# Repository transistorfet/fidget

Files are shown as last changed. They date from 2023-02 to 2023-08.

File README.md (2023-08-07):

Fidget - The FPGA Widget
========================

###### *Started January 5, 2023*

This project is an experiment in making a board using a Lattice iCE40 FPGA in a surface mount
package (LQFP-144).  It has bus connectors to allow it to be hooked up to one of the
[Computie](https://jabberwocky.ca/projects/computie/) single board computers, to be used as either a
debug monitor to replace the arduino supervisor, or as a generic expansion device for the computers.
I'd also like to be able to use it more generically as well, for example as a logic analyzer, which
is why it's called a widget.

It needs to have bus transceivers to level convert between the 5V signals of the Computie expansion
bus, and the 3.3V I/O pins of the FPGA.  To save on I/Os, the address and data bus lines are
multiplexed using the level-converting transceivers.  I also added the latches necessary to make a
request on the bus.  Without the latches, the device will only be able to receive bus requests but
not make them.

The basic design of the USB and power supply circuitry was mostly copied from the [TinyFPGA
BX](https://www.crowdsupply.com/tinyfpga/tinyfpga-ax-bx) development board.  I bought one back in
early 2020, and have an environment set up for developing for it.  I was able to reuse the
bootloader and upload utility from that to accelerate the bring-up of this board.  I highly
recommend checking it out, especially since it sounds like they will have more boards for sale soon
in 2023.  It's an excellent affordable open source board which is great for experimenting with
verilog and FPGAs.

The schematics can be seen online
[here](https://github.com/transistorfet/fidget/blob/main/hardware/Fidget/Fidget.pdf) or in KiCAD.

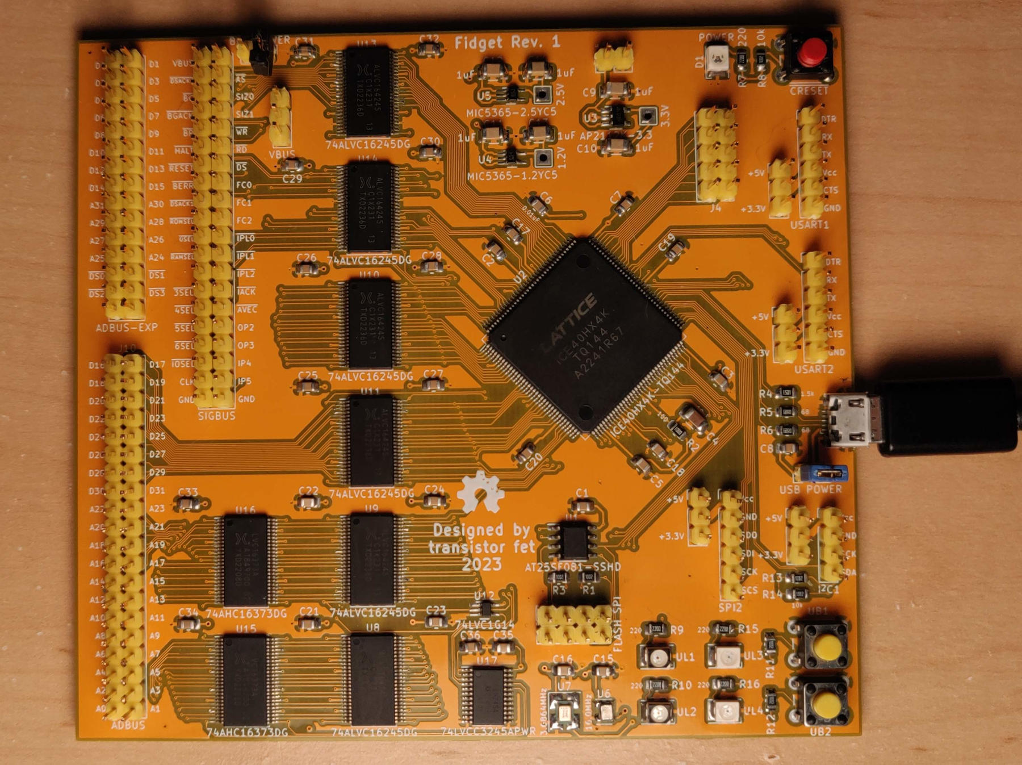
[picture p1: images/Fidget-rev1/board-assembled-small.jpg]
Fidget Revision 1, assembled and working


This repository uses submodules, and can be cloned using:
```
git clone --recurse-submodules git@github.com:transistorfet/fidget.git
```

Building the Board
------------------

It was surprisingly easy to build, although my attempts at documenting the soldering of the
transceivers resulted in more mistakes than it was worth.  I had solder bridges on every chip that
required some solder wick, and I had a few chips that were crooked enough that I decided to just use
the hot air rework station to remove them and resolder them.  The FPGA was actually much easier to
solder by comparison.  The other parts I had trouble with were the oscillators, which come in a
module on a tiny circuit board with castellated pins on the edges.  The 3.6864 Mhz one was easy
because the footprint turned out to be way bigger than the chip, but the 16 MHz one was the right
size for the part but with not enough clearance for hand soldering.  In future revisions I'll have
to make the footprint bigger.

I started with the 3.3V regulator and tested it with a bench power supply at 5V to verify that I was
getting 3.3V output, which is used by the transceivers.  I then soldered the transceivers and
latches at once, along with their caps, and tested at the end of that.  I put the SPI flash and
oscillators on and tested those with the bench supply to make sure I was getting signal.  The 16 Mhz
oscillator needed a lot of reworking and desoldering.

With the SPI flash chip in, I programmed it (see below).  I also put the other voltage regulators in
and tested them before soldering the FPGA.  With the all the power good, I put the other LEDs,
buttons on, as well as the FPGA itself with its associated caps.  After checking for shorts, I
tested it to see what would happen.  Surprisingly it worked, with the bootloader slowly blinking one
of the LEDs to indicate it was running, so the configuration I had written to the flash chip was
good.  I then put on the remaining headers which were the last components to solder.

At the end, and between the two days I was assembling, I cleaned the flux off with a toothbrush and
some soap and/or rubbing alcohol.  I then blow dried the board to make sure the water under the
chips was dry before it had a chance to corrode any pins.  It's best to not get the board too hot
when doing this.

I like to use water soluble liquid flux.  The No Clean stuff is much harder to clean up after, but
it doesn't have to be cleaned off, where as the water soluble stuff can corrode the pins if it's not
cleaned off, but works better and is easy to clean.

For soldering, I use a soldering tip that's cone-shaped but cut off at an angle to form a large flat
surface.  It heats the pad on the board better than a round tip, which gives a good solder
connection for SMT components, even though it's wider than individual pins.  The solder mask and
flux make the solder flow well and not bridge.  I have a Quick 861DW hot air rework station for when
I make mistakes, but I only needed to use it twice, once to remove the 3 crooked
transceivers/latches, which probably would have been ok if I had left them, and once to remove the
16 MHz oscillator.

Initializing the Board
----------------------

To load the initial bootloader, I used [spi-flash-programmer](https://github.com/nfd/spi-flash-programmer)
and an [AdaFruit QT Py](https://www.adafruit.com/product/4600) I had laying around, which just
happened to be the most convenient 3.3V Arduino-compatible board I had available, but any 3.3V
Arduino will do.  I uploaded the flash programmer to it, but I needed to adjust the SPI speed
because the default was too high for the long dupont wires I used to connect it to Fidget.

I programmed the SPI chip in circuit before I soldered the FPGA in place, just in case they
interfered, which was a good idea because they did interfere.  With the FPGA in circuit, the RESET
button needs to be held for the duration of SPI programming (preferably for the whole time the
Arduino is connected), or it won't work.

I connected the SCK, SDI, and SDO signals on the Arduino to the SPI Flash header on Fidget, along
with a general purpose I/O (I used A0/D0) connected to the CS pin on the header.  I also connected
power from the QT Py to power the board while programming, which does also power the FPGA and
transceivers, but since the QT Py has the exact same 3.3V regulator I used, as it turns out, which
is capable of 600mA, it has no problem powering the whole board up.

I compiled the [TinyFPGA Bootloader](https://github.com/tinyfpga/TinyFPGA-Bootloader), using a board
configuration based on the BX, but with the device to compile to changed (hx4k-tq144) and pin
assignments changed.  Compiling it with `make` produces a fw.bin file, as well as bootloader_0.bin,
and bootloader_1.bin.

As it turned out, I needed to write fw.bin to the start of the device, even though at the end of
compiling it says to write bootloader_0.bin to 0xa0, and bootloader_1.bin to 0x28000.  Before I put
the chip on, I wrote the two images separately with some zero padding at the start, and for some
reason it still worked when I put the chip on.  I later reprogrammed it once I was able to program
in-circuit after some unrelated problems with a wire not making good connection.

The first 0xa0 bytes of data is actually the boot vector table used by the FPGA itself to locate the
configurations in the remaining part of memory.  It has 5 entries, one for the cold boot
configuration to load at startup, and the remaining 4 for the selectable warm boot configurations.
The TinyFPGA bootloader only uses 2 configurations, the bootloader itself, and the user program.,
and puts the bootloader as the target of all the other entries.  For more info on the boot vectors,
check out [https://umarcor.github.io/warmboot/](https://umarcor.github.io/warmboot/).

The bootloader didn't work at first.  It would raise uncaught exceptions everywhere, but it turned
out to be that it was trying to load meta data and there wasn't any programmed into the SPI Flash.
I didn't know this was needed, and for some reason using the bootloader to program the security page
would say that it worked but would always read back 0xFFs.  I haven't tried putting it in user
memory, which the bootloader also checks for metadata.  I just hacked it to use the default TinyFPGA
BX meta data and it programs just fine.  I'll fix it properly, eventually.

I had some other issues with the blinking led test, where it just wouldn't work, but it turned out
to be that I had the HX1K device still configured, from before I decide to switch to the HX4K.  The
1k device wasn't big enough to house the configuration for the bootloader, which left me kind of
hooped unless I switched.  The 4ks aren't as easily available but I managed to buy a few from
another distributor I don't normally buy from.

Now I can upload configuration through USB using tinyprog and the bootloader!

```sh
python3 spi_flash_programmer_client.py -d /dev/ttyACM2 --io 0 write -f fw.bin -l 0x28000 --pad 0xff
```

Loading through the Bootloader
------------------------------

I currently have the meta data hacked in, but it can be written to the security pages or to an area
of the SPI Flash.  It's in `rtl/TinyFPGA-Bootloader/boards/Fidget/metadata.json`.  With that, it
should recognize the boot loader and upload

From the `rtl/TinyFPGA-Bootloader/programmer`:
```sh
python3 -m tinyprog -p ../../blinking_led/fidget.bin
```

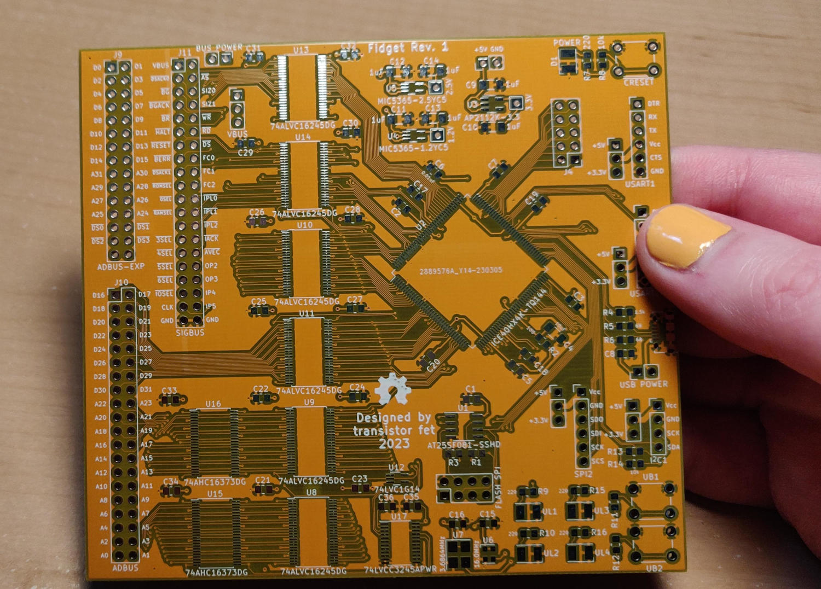
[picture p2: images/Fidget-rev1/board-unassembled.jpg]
Fidget Revision 1 bare boards, with matching fingers


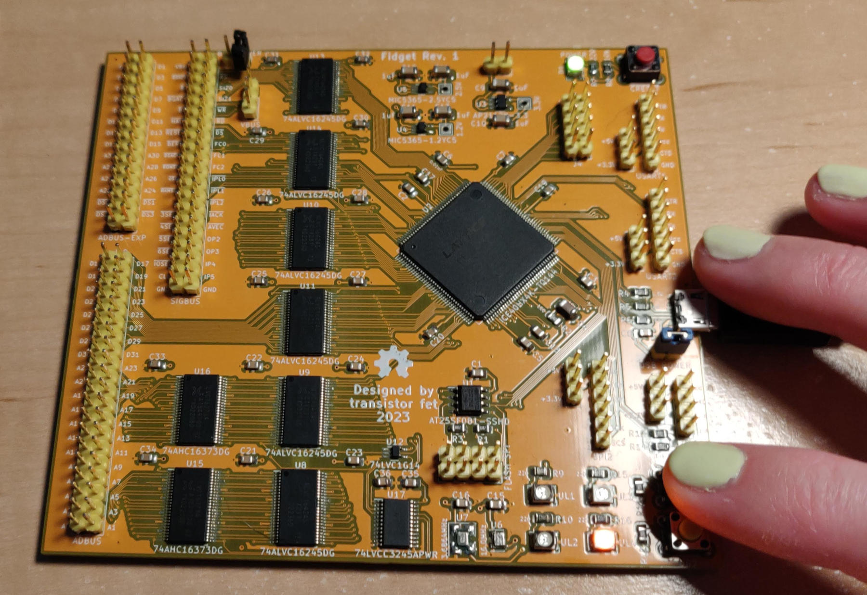
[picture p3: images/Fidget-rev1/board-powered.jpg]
Fidget Revision 1, with blinking lights


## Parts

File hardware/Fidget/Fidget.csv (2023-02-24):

Source: | /media/work/fidget/hardware/Fidget/Fidget.kicad_sch
Date: | Thu 23 Feb 2023 10:14:40 PM
Tool: | Eeschema 6.0.11+dfsg-1
Generator: | /usr/share/kicad/plugins/bom_csv_grouped_by_value_with_fp.py
Component Count: | 98
Ref | Qnty | Value | Cmp name | Footprint | Description | Vendor
C1, C2, C3, C5, C7, C8, C15, C16, C17, C18, C19, C20, C21, C22, C23, C24, C25, C26, C27, C28, C29, C30, C31, C32, C33, C34, C35, C36, | 28 | 0.1uF | C_Small | Capacitor_SMD:C_0805_2012Metric_Pad1.18x1.45mm_HandSolder | Unpolarized capacitor, small symbol
C4, | 1 | 10uF | C_Polarized_Small_US | Capacitor_SMD:C_1206_3216Metric_Pad1.33x1.80mm_HandSolder | Polarized capacitor, small US symbol
C6, | 1 | 0.01uF | C_Small | Capacitor_SMD:C_0805_2012Metric_Pad1.18x1.45mm_HandSolder | Unpolarized capacitor, small symbol
C9, C10, C11, C12, C13, C14, | 6 | 1uF | C_Small | Capacitor_SMD:C_1206_3216Metric_Pad1.33x1.80mm_HandSolder | Unpolarized capacitor, small symbol
D1, | 1 | POWER | LED | LED_SMD:LED_PLCC-2_3.4x3.0mm_KA | Light emitting diode
D2, | 1 | UL1 | LED | LED_SMD:LED_PLCC-2_3.4x3.0mm_KA | Light emitting diode
D3, | 1 | UL2 | LED | LED_SMD:LED_PLCC-2_3.4x3.0mm_KA | Light emitting diode
D4, | 1 | UL3 | LED | LED_SMD:LED_PLCC-2_3.4x3.0mm_KA | Light emitting diode
D5, | 1 | UL4 | LED | LED_SMD:LED_PLCC-2_3.4x3.0mm_KA | Light emitting diode
J1, | 1 | FLASH SPI | Conn_02x04_Odd_Even | Connector_PinHeader_2.54mm:PinHeader_2x04_P2.54mm_Vertical | Generic connector, double row, 02x04, odd/even pin numbering scheme (row 1 odd numbers, row 2 even numbers), script generated (kicad-library-utils/schlib/autogen/connector/)
J2, | 1 | USB_B_Micro | USB_B_Micro | Connector_USB:USB_Micro-B_Amphenol_10118194_Horizontal | USB Micro Type B connector
J3, | 1 | +5Vin | Conn_01x02 | Connector_PinHeader_2.54mm:PinHeader_1x02_P2.54mm_Vertical | Generic connector, single row, 01x02, script generated (kicad-library-utils/schlib/autogen/connector/)
J4, | 1 | EXT I/O | Conn_01x10 | Connector_PinHeader_2.54mm:PinHeader_2x05_P2.54mm_Vertical | Generic connector, single row, 01x10, script generated (kicad-library-utils/schlib/autogen/connector/)
J5, | 1 | SPI2 | Conn_01x06 | Connector_PinHeader_2.54mm:PinHeader_1x06_P2.54mm_Vertical | Generic connector, single row, 01x06, script generated (kicad-library-utils/schlib/autogen/connector/)
J6, | 1 | USART1 | Conn_01x06 | Connector_PinHeader_2.54mm:PinHeader_1x06_P2.54mm_Vertical | Generic connector, single row, 01x06, script generated (kicad-library-utils/schlib/autogen/connector/)
J7, | 1 | I^{2}C1 | Conn_01x04 | Connector_PinHeader_2.54mm:PinHeader_1x04_P2.54mm_Vertical | Generic connector, single row, 01x04, script generated (kicad-library-utils/schlib/autogen/connector/)
J8, | 1 | USART2 | Conn_01x06 | Connector_PinHeader_2.54mm:PinHeader_1x06_P2.54mm_Vertical | Generic connector, single row, 01x06, script generated (kicad-library-utils/schlib/autogen/connector/)
J9, | 1 | ADBUS-EXP | Conn_02x15_Odd_Even | Connector_PinHeader_2.54mm:PinHeader_2x15_P2.54mm_Vertical | Generic connector, double row, 02x15, odd/even pin numbering scheme (row 1 odd numbers, row 2 even numbers), script generated (kicad-library-utils/schlib/autogen/connector/)
J10, | 1 | ADBUS | Conn_02x20_Odd_Even | Connector_PinHeader_2.54mm:PinHeader_2x20_P2.54mm_Vertical | Generic connector, double row, 02x20, odd/even pin numbering scheme (row 1 odd numbers, row 2 even numbers), script generated (kicad-library-utils/schlib/autogen/connector/)
J11, | 1 | SIGBUS | Conn_02x20_Odd_Even | Connector_PinHeader_2.54mm:PinHeader_2x20_P2.54mm_Vertical | Generic connector, double row, 02x20, odd/even pin numbering scheme (row 1 odd numbers, row 2 even numbers), script generated (kicad-library-utils/schlib/autogen/connector/)
JP2, | 1 | USB POWER | Jumper_2_Open | Connector_PinHeader_2.54mm:PinHeader_1x02_P2.54mm_Vertical | Jumper, 2-pole, open
JP3, | 1 | VBUS | Jumper_3_Bridged12 | Connector_PinHeader_2.54mm:PinHeader_1x03_P2.54mm_Vertical | Jumper, 3-pole, pins 1+2 closed/bridged
JP4, | 1 | VUSART1 | Jumper_3_Bridged12 | Connector_PinHeader_2.54mm:PinHeader_1x03_P2.54mm_Vertical | Jumper, 3-pole, pins 1+2 closed/bridged
JP5, | 1 | VSPI2 | Jumper_3_Bridged12 | Connector_PinHeader_2.54mm:PinHeader_1x03_P2.54mm_Vertical | Jumper, 3-pole, pins 1+2 closed/bridged
JP6, | 1 | VUSART2 | Jumper_3_Bridged12 | Connector_PinHeader_2.54mm:PinHeader_1x03_P2.54mm_Vertical | Jumper, 3-pole, pins 1+2 closed/bridged
JP7, | 1 | VI^{2}C1 | Jumper_3_Bridged12 | Connector_PinHeader_2.54mm:PinHeader_1x03_P2.54mm_Vertical | Jumper, 3-pole, pins 1+2 closed/bridged
JP8, | 1 | BUS POWER | Jumper_2_Bridged | Connector_PinHeader_2.54mm:PinHeader_1x02_P2.54mm_Vertical | Jumper, 2-pole, closed/bridged
R1, R3, R8, R11, R12, R13, R14, | 7 | 10k | R_Small | Resistor_SMD:R_0805_2012Metric_Pad1.20x1.40mm_HandSolder | Resistor, small symbol
R2, | 1 | 100 | R_Small | Resistor_SMD:R_0805_2012Metric_Pad1.20x1.40mm_HandSolder | Resistor, small symbol
R4, | 1 | 1.5k | R_Small | Resistor_SMD:R_0805_2012Metric_Pad1.20x1.40mm_HandSolder | Resistor, small symbol
R5, R6, | 2 | 68 | R_Small | Resistor_SMD:R_0805_2012Metric_Pad1.20x1.40mm_HandSolder | Resistor, small symbol
R7, R9, R10, R15, R16, | 5 | 220 | R_Small | Resistor_SMD:R_0805_2012Metric_Pad1.20x1.40mm_HandSolder | Resistor, small symbol
SW1, | 1 | ~{CRESET} | SW_Push | Button_Switch_THT:SW_PUSH_6mm | Push button switch, generic, two pins
SW2, | 1 | UB1 | SW_Push | Button_Switch_THT:SW_PUSH_6mm | Push button switch, generic, two pins
SW3, | 1 | UB2 | SW_Push | Button_Switch_THT:SW_PUSH_6mm | Push button switch, generic, two pins
TP1, | 1 | 3.3V | TestPoint | TestPoint:TestPoint_THTPad_2.0x2.0mm_Drill1.0mm | test point
TP2, | 1 | 1.2V | TestPoint | TestPoint:TestPoint_THTPad_2.0x2.0mm_Drill1.0mm | test point
TP3, | 1 | 2.5V | TestPoint | TestPoint:TestPoint_THTPad_2.0x2.0mm_Drill1.0mm | test point
U1, | 1 | AT25SF081-SSHD | AT25SF081-SSHD-X | Package_SO:SOIC-8_3.9x4.9mm_P1.27mm | 8-Mbit, 2.5V Minimum SPI Serial Flash Memory with Dual-I/O and Quad-I/O Support, SOIC-8
U2, | 1 | ICE40HX4K-TQ144 | ICE40HX4K-TQ144 | Package_QFP:TQFP-144_20x20mm_P0.5mm | iCE40 HX FPGA, 3520 LUTs, 1.2V, TQFP-144
U3, | 1 | AP2112K-3.3 | AP2112K-3.3 | Package_TO_SOT_SMD:SOT-23-5_HandSoldering | 600mA low dropout linear regulator, with enable pin, 3.8V-6V input voltage range, 3.3V fixed positive output, SOT-23-5
U4, | 1 | MIC5365-1.2YC5 | MIC5365-3.3YC5 | Package_TO_SOT_SMD:SOT-353_SC-70-5_Handsoldering | 150mA Low-dropout Voltage Regulator, Vout 3.3V, Vin up to 5.5V, SC-70-5
U5, | 1 | MIC5365-2.5YC5 | MIC5365-3.3YC5 | Package_TO_SOT_SMD:SOT-353_SC-70-5_Handsoldering | 150mA Low-dropout Voltage Regulator, Vout 3.3V, Vin up to 5.5V, SC-70-5
U6, | 1 | KC2520Z16.0000C15XXK | KC2520Z | Oscillator:Oscillator_SMD_Kyocera_KC2520Z-4Pin_2.5x2.0mm | 1.8432MHz ~ 125MHz Crystal Oscillator
U7, | 1 | KC3225Z3.68640C1KX00 | KC2520Z | Oscillator:Oscillator_SMD_Kyocera_KC2520Z-4Pin_2.5x2.0mm | 1.8432MHz ~ 125MHz Crystal Oscillator
U8, U9, U10, U11, U13, U14, | 6 | 74ALVC16245DG | 74ALVC16245DG | Package_SO:TSSOP-48_6.1x12.5mm_P0.5mm | 16-Bit Dual Supply Bidirectional Translating Transceiver with 5V Tolerant Inputs and Outputs, TSSOP-48
U12, | 1 | 74LVC1G14 | 74LVC1G14 | Package_TO_SOT_SMD:SOT-353_SC-70-5_Handsoldering | Single Schmitt NOT Gate, Low-Voltage CMOS
U15, U16, | 2 | 74AHC16373DG | 74AHC16373DG | Package_SO:TSSOP-48_6.1x12.5mm_P0.5mm | 16-Bit D-Type Transparent Latch Tri-State, TSSOP-48
U17, | 1 | 74LVCC3245APWR | 74LVCC3245APWR | Package_SO:TSSOP-24_4.4x7.8mm_P0.65mm | 8-Bit Dual Supply Bidirectional Translating Transceiver with 5V Tolerant Inputs and Outputs, TSSOP-24

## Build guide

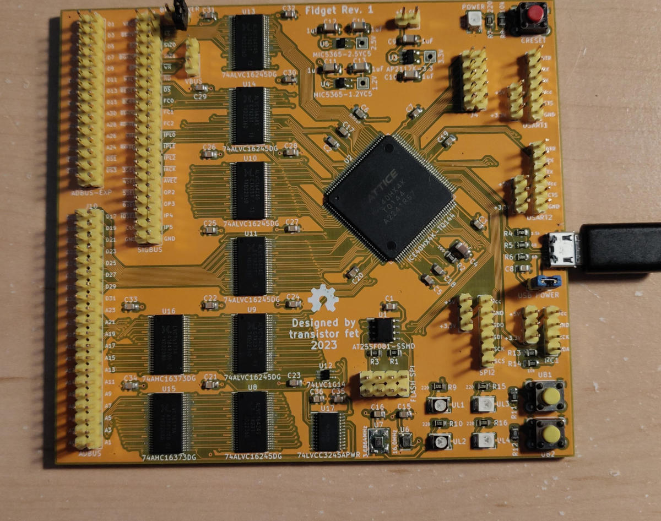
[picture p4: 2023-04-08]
images/Fidget-rev1/board-assembled-alt.jpg

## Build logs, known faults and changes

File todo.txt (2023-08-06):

* you need a way to make the dump stop, like have the button latch so it only dumps once
* add RTS/CTS to serial ports

* can you somehow make it possible to reset remotely, or through a configured bit, so it's easier to reprogram?

Rtl:

  * can you/should you use the SB_DFFR block, D-type Flip Flop with Async Reset, to implement user-resettable flags for error and
    break and such, rather than auto-resetting it

Hardware:

  * I still haven't been able to write to the security page, or to otherwise make the metadata thing work.  It says it's programming
    it's but it then it reads back as FFs.  The programmer for the serial header doesn't support the security page, so I'll have to
    add it if I want to try to make that work.  Should probably get that sorted before I make another board

  * the DSACK and BERR signals can't really be satisfactorily handled by the transceivers.  They should probably be using an
    open collector, which might actually be ok to use a 3.3V chip with the 5V bus because it should only ever be connecting
    ground to the pin, and be high impedence otherwise... either way you should have a separate chip for that, and you could
    get rid of the extra HC245 transceiver
  * instead of using the invertor gate for the control signals, which didn't work, you could use it for the address and data
    output enables so that only one is ever turned on at the same time, since you had issues with the chips burning up due to
    a misconfiguration

  * what if the next iteration you add an arm microcontroller, either a SAMD or STM32

  * figure out what you need to do about the SPI disconnect to program the chip
  * should I wire up the WP and HOLD signals of the flash to FPGA pins?

  * what kind of ports, and easy extensions, should the board have?
    - it already have the primary USB interface
    - 6 pin Serial-to-USB interface (4 I/O)
    - buttons and LEDs for general use
    - headers that can be used for SPI, I2C, and others, for interfacing with offboard devices (2 I/O for I2C, 4 I/O for SPI)
    - type A USB for a USB Host? (an additional 2-3 I/O)
    - perhaps in a later revision, I can add Ethernet and SVGA/HDMI (although I think the chip isn't big enough for video gen)
    - later, could impl an fm synth in fpga with dac audio bitstream as output

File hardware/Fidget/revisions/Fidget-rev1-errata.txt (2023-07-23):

Revision 1 Errata and Notes
===========================

- the silkscreen for the VBUS voltage jumper was forgotten.  It should label each position as 5V
  or 3.3V

- the horizontal back to back capacitors in the power supplies and elsewhere are a little hard to
  solder.  Not really hard, just a little harder, especially the 1uF caps which are quite tall

- there's a surprising amount of inrush current, such that I have to set the current limit to 350mA
  to get it to start without the FPGA.  I take it this is caused by the bypass capacitors
  chips on

- the bus power jumper is awfully close to the ribbon cable connector.  It should be fine, but I'd
  prefer it being further away, if I designed this again

- the 16 MHz oscillator's footprint should be a lot bigger because it was very difficult to hand
  solder.  The 3.6864 MHz one was much easier because it turned out the chips I got weren't much
  bigger than the 16 MHz ones, but the footprint was for a much bigger chip, and also had enough
  overlap, so that the 4 corners had lots of solder pad to heat up

- it would have helped to have silkscreen labels for the SPI Flash connector

- it would have been more helpful to have the CRESET either wired to a pin on the SPI Flash
  connector or at least just beside the button, so it could be forcefully held low for programming
  the SPI flash.  As it is, the reset button must be held for the whole time it's programming

- the send/receive signal means that the DSACK and BERR signals must always be outputs, which
  interferes with other devices sharing the bus, making it hard to act as a generic peripheral.
  The transceiver should just have a separate I/O to control the direction of each half

- USART flow control signals should be named appropriately on the FPGA pins, like the TX and RX
  pins which are named correctly on the FPGA input but the silkscreen matches what the
  USB-to-Serial convertors label the pins as.  I've changed the pin mapping to match what they
  should be.  DTR should be renamed CTS, and CTS should be renamed RTS, so they always match the
  local endpoint, and they're cross-wired like the RX/TX pins for the other end.

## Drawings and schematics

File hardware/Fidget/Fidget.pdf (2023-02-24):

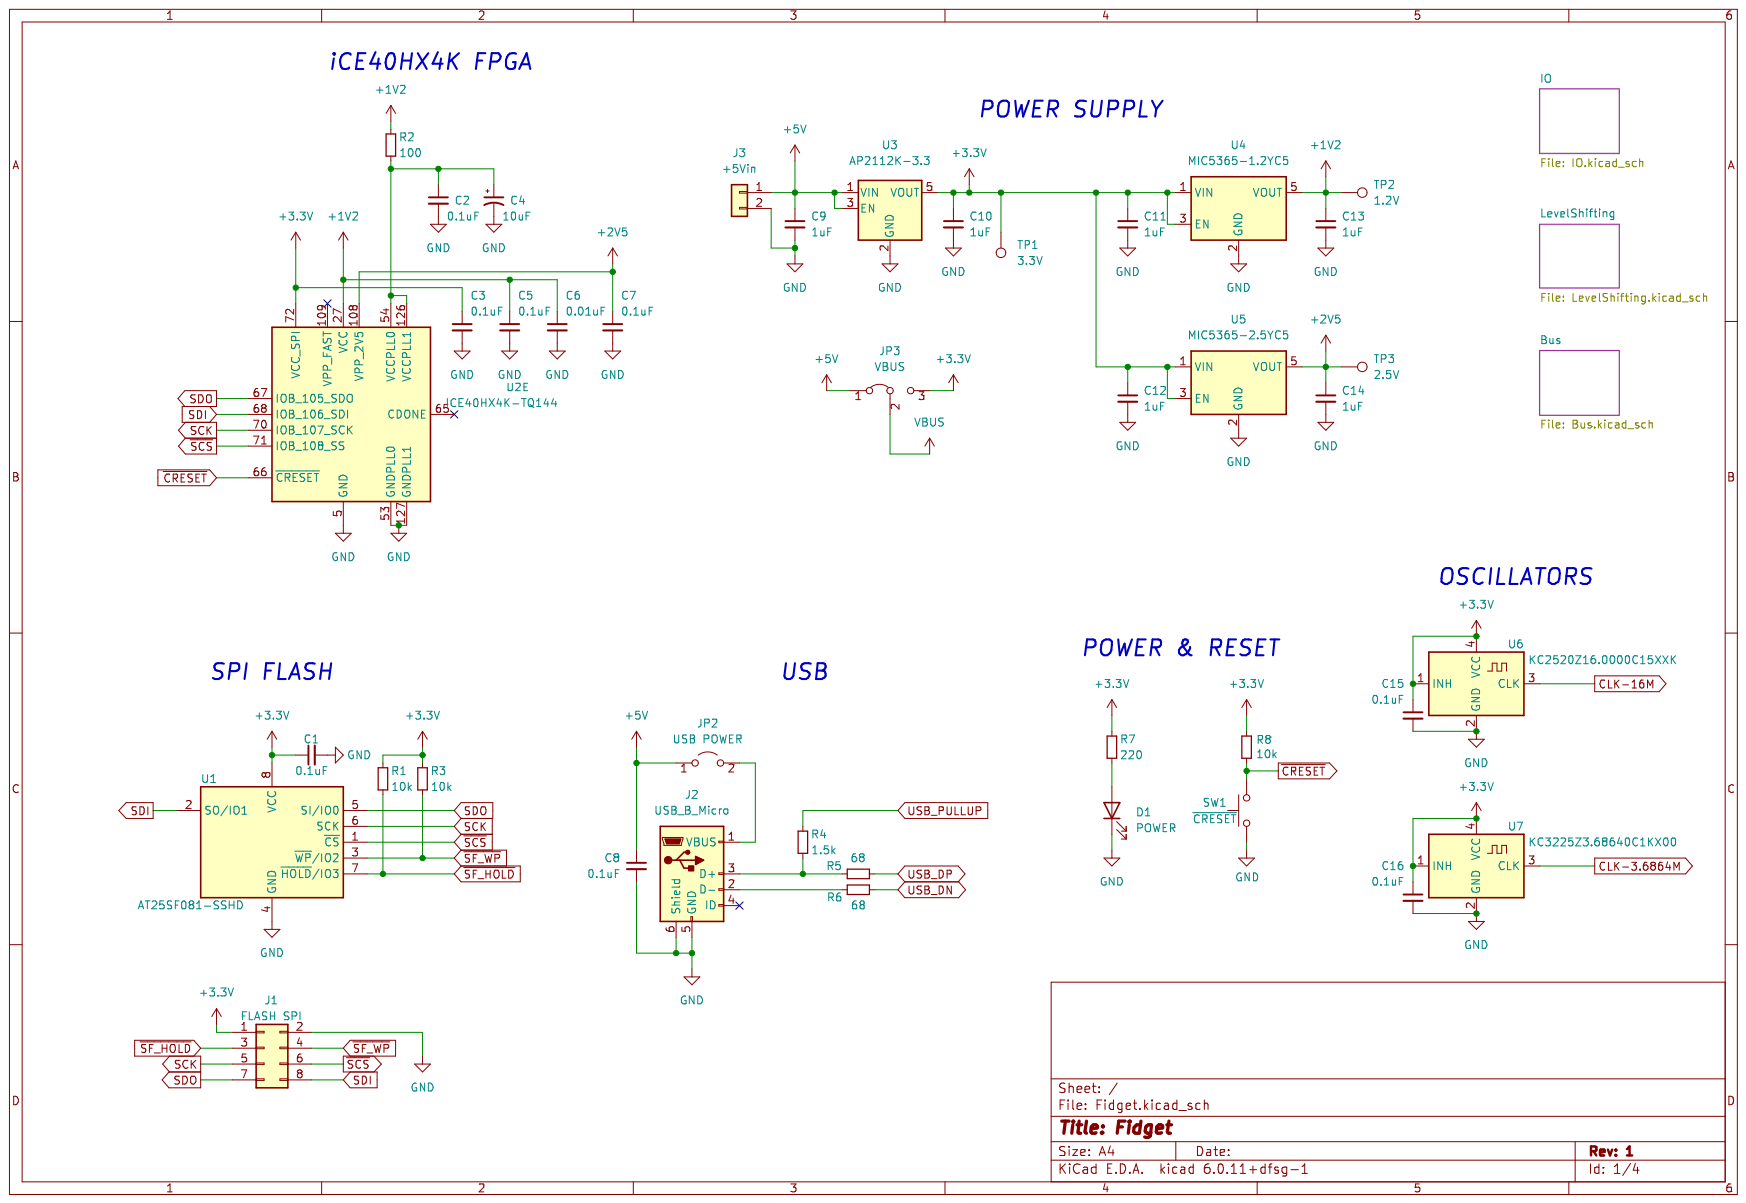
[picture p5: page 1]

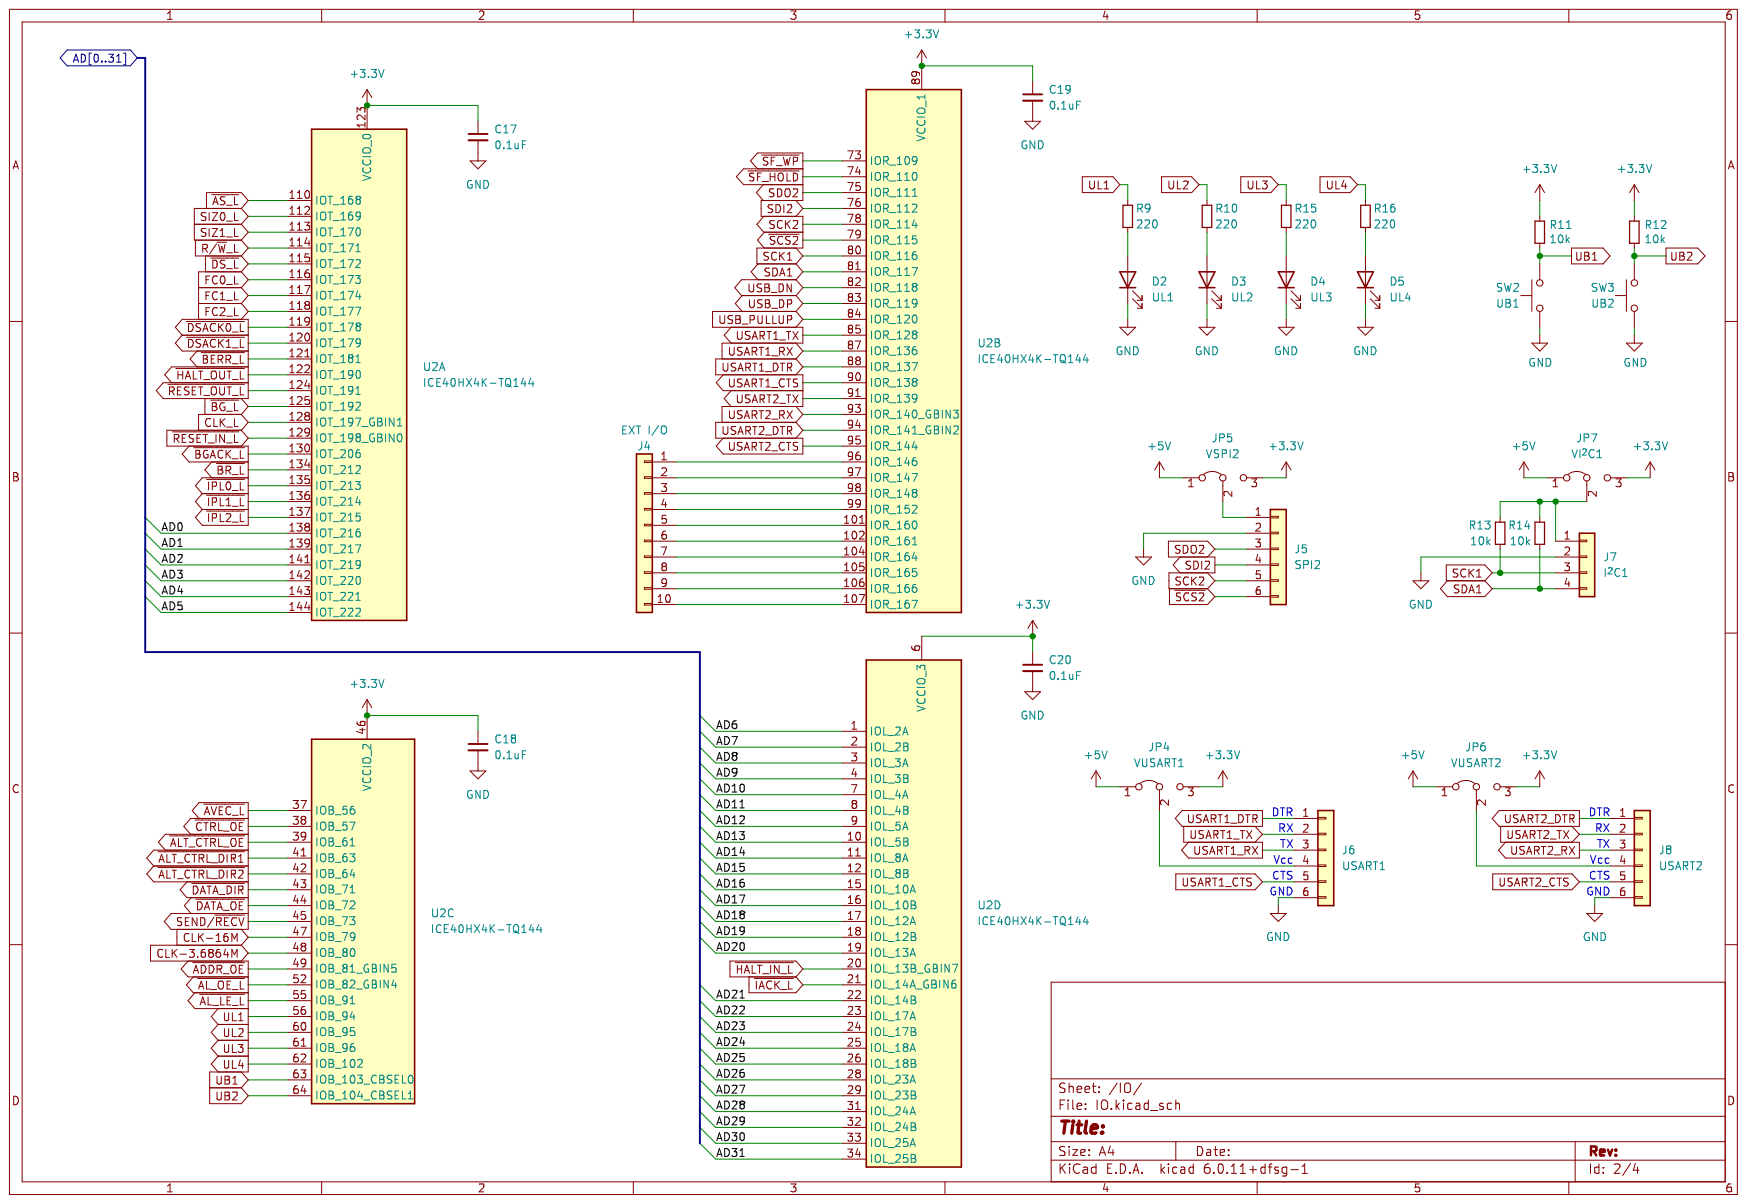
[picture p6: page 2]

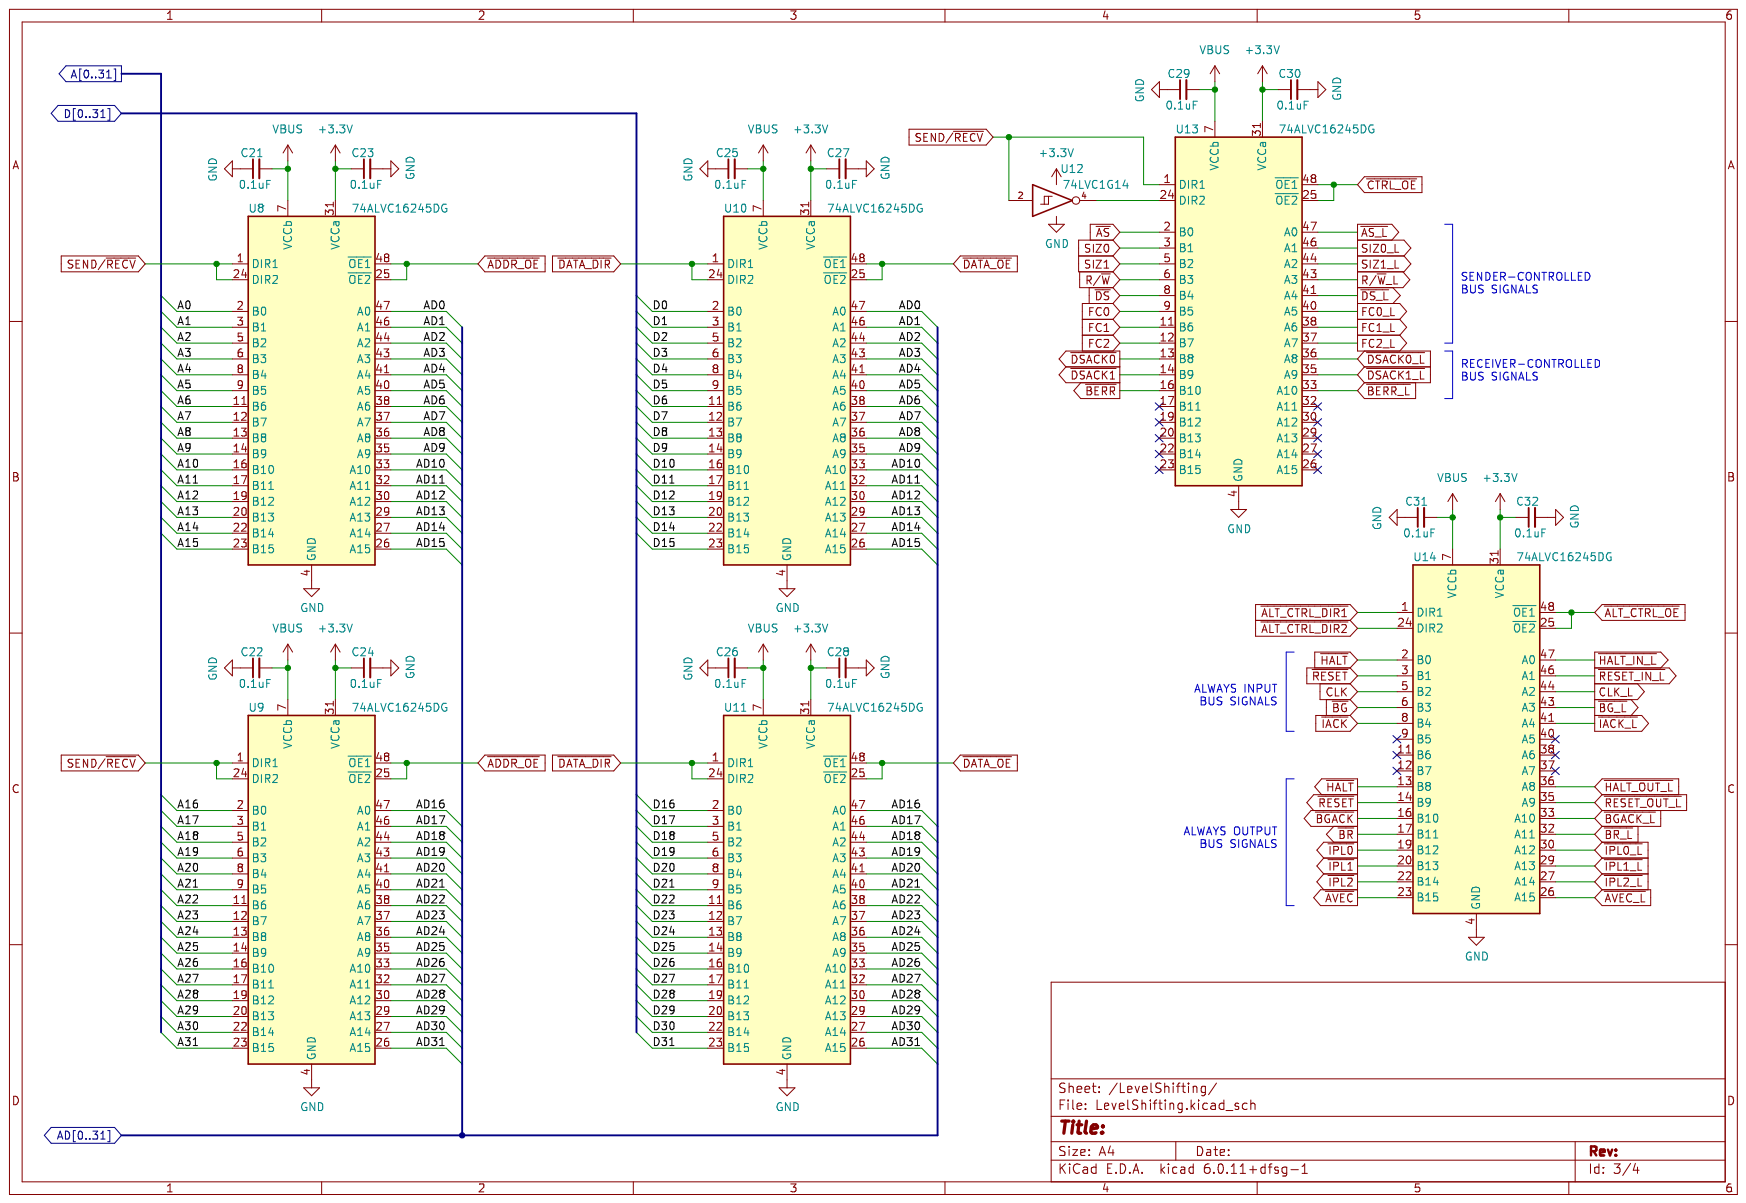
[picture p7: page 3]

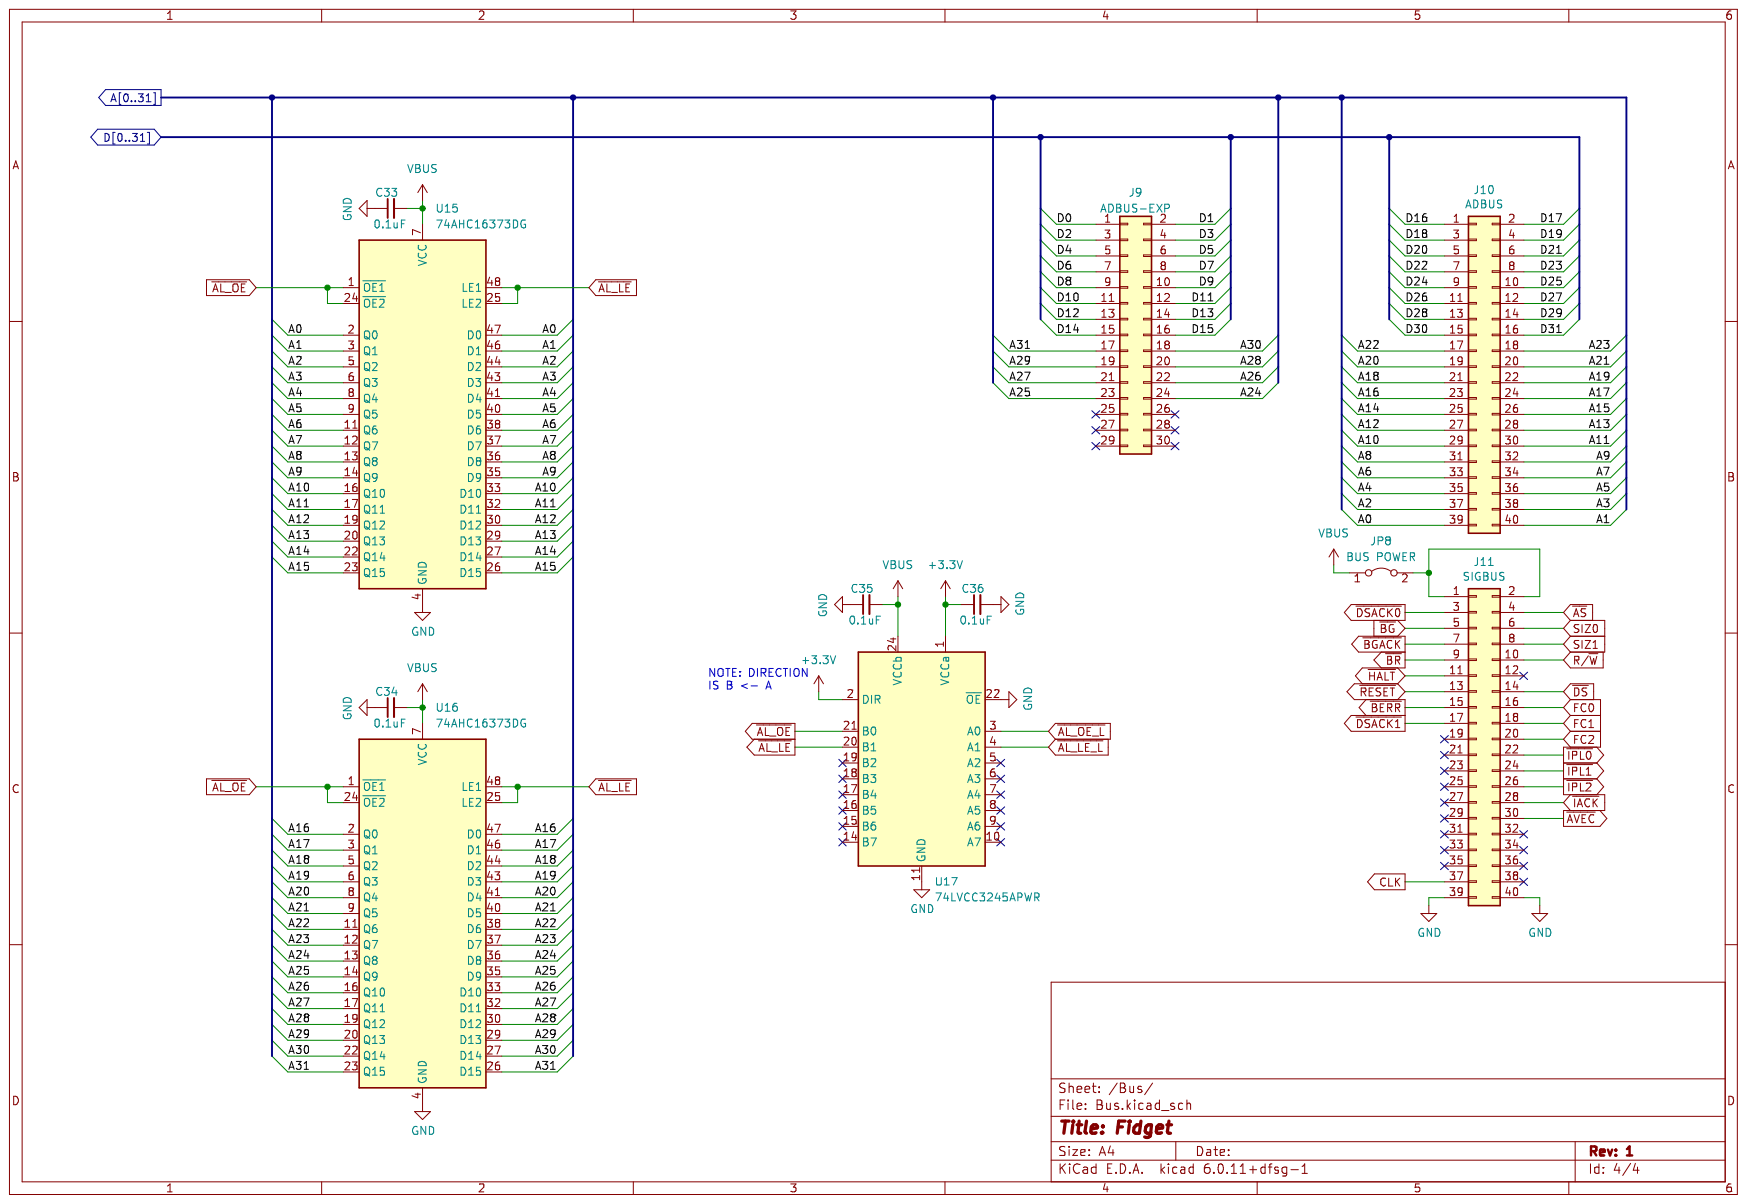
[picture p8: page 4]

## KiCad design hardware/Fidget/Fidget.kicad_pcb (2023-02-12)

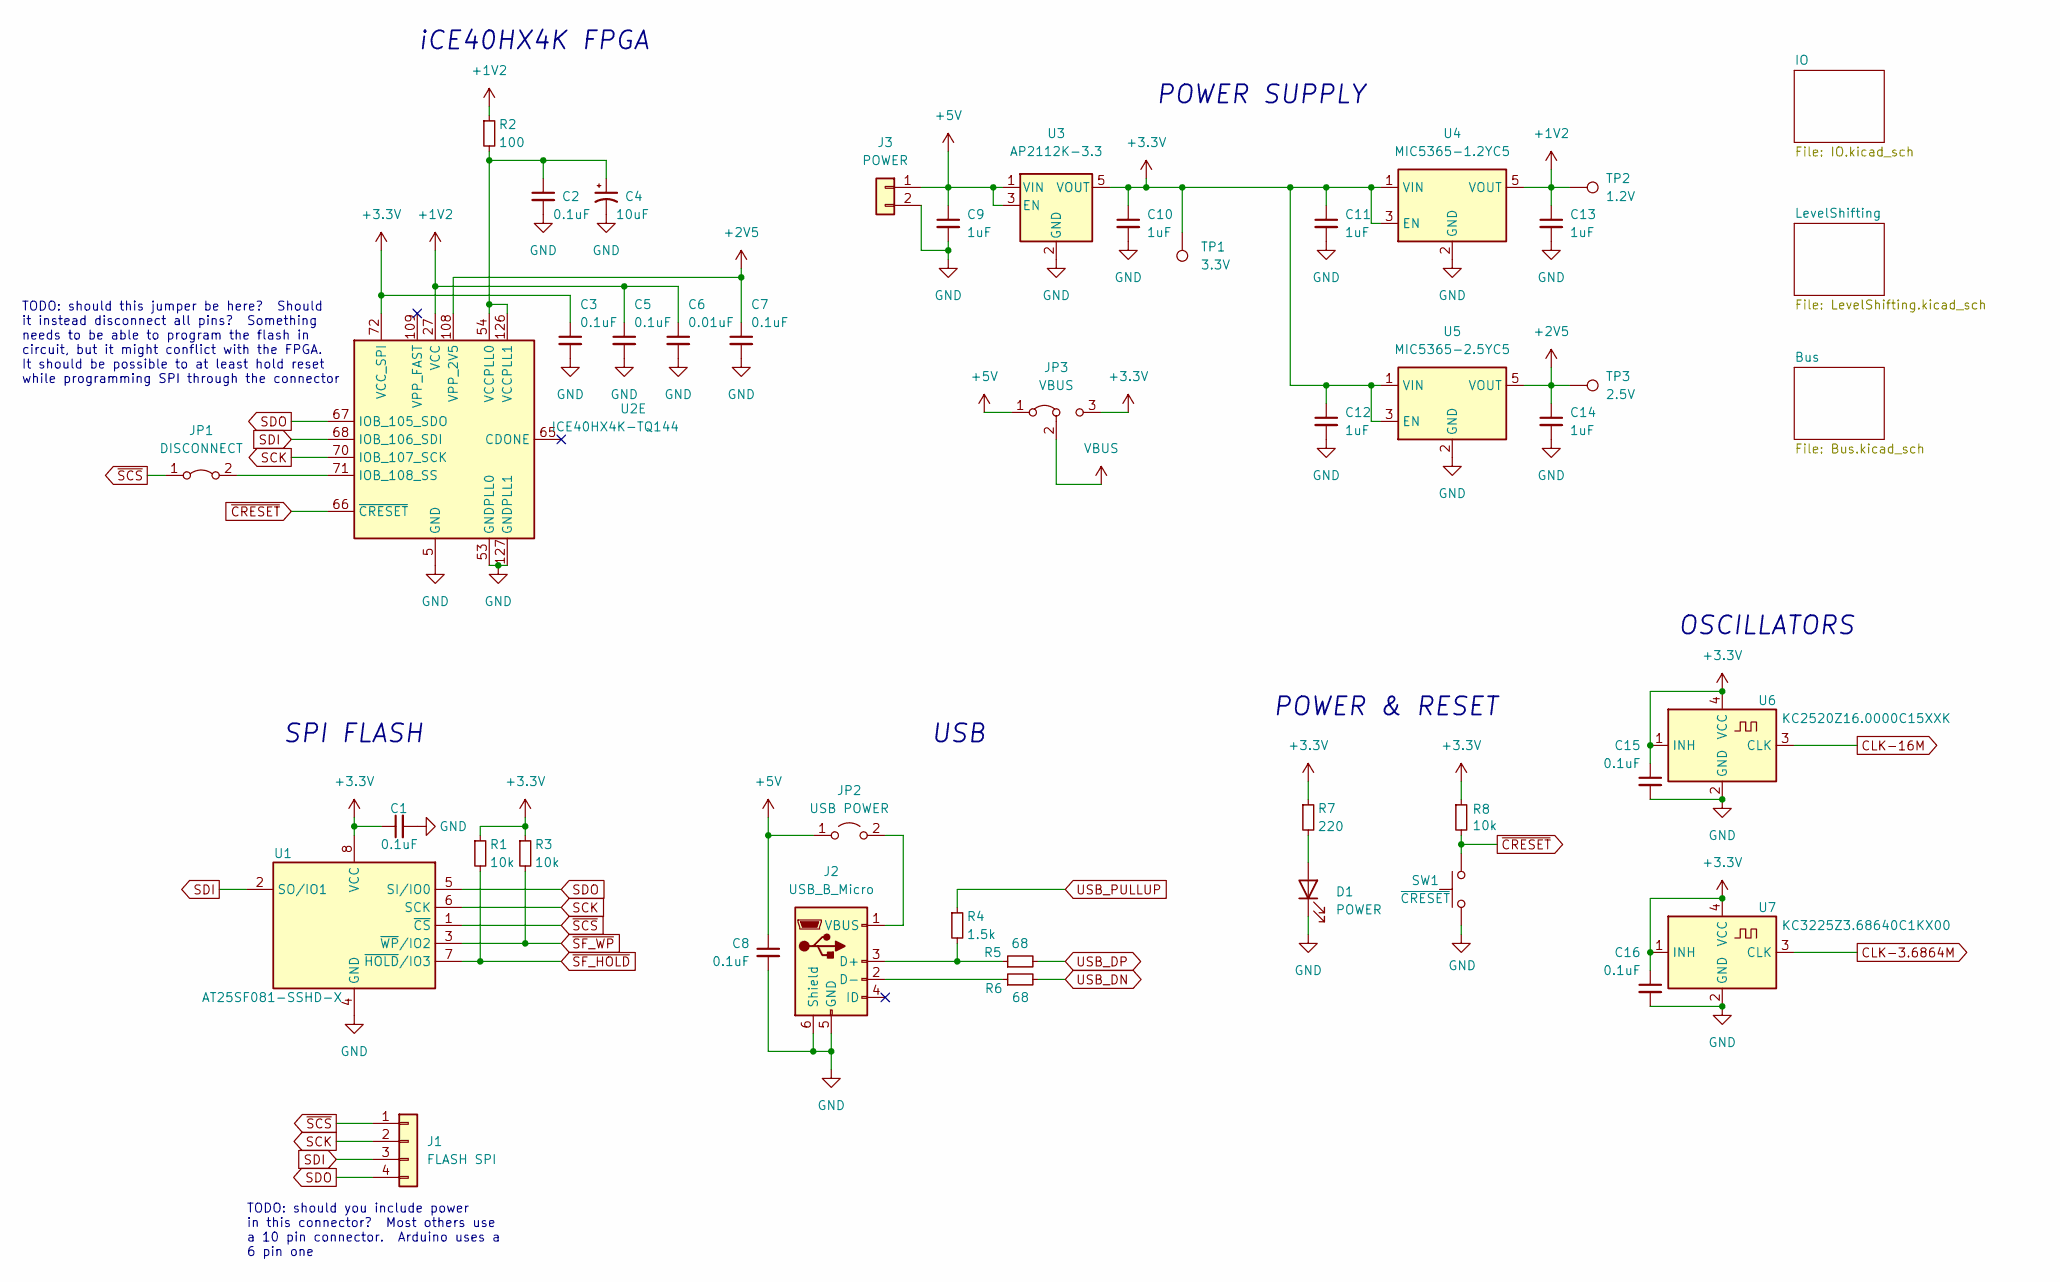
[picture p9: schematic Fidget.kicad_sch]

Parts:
C1, C2, C3, C5, C7, C8, C15, C16: 0.1uF; C_0805_2012Metric_Pad1.18x1.45mm_HandSolder
C4: 10uF; C_1206_3216Metric_Pad1.33x1.80mm_HandSolder
C6: 0.01uF; C_0805_2012Metric_Pad1.18x1.45mm_HandSolder
C9, C10, C11, C12, C13, C14: 1uF; C_1206_3216Metric_Pad1.33x1.80mm_HandSolder
D1: POWER
J1: FLASH SPI; PinHeader_1x04_P2.54mm_Vertical
J2: USB_B_Micro; USB_Micro-B_Amphenol_10118194_Horizontal
J3: POWER; PinHeader_1x02_P2.54mm_Vertical
JP1: DISCONNECT; PinHeader_1x02_P2.54mm_Vertical
JP2: USB POWER; PinHeader_1x02_P2.54mm_Vertical
JP3: VBUS; PinHeader_1x03_P2.54mm_Vertical
R1, R3: 10k; R_0805_2012Metric_Pad1.20x1.40mm_HandSolder
R2: 100; R_0805_2012Metric_Pad1.20x1.40mm_HandSolder
R4: 1.5k; R_0805_2012Metric_Pad1.20x1.40mm_HandSolder
R5, R6: 68; R_0805_2012Metric_Pad1.20x1.40mm_HandSolder
R7: 220; R_Axial_DIN0204_L3.6mm_D1.6mm_P5.08mm_Horizontal
R8: 10k; R_Axial_DIN0204_L3.6mm_D1.6mm_P5.08mm_Horizontal
SW1: ~{CRESET}; SW_PUSH_6mm
TP1: 3.3V; TestPoint_THTPad_2.0x2.0mm_Drill1.0mm
TP2: 1.2V; TestPoint_THTPad_2.0x2.0mm_Drill1.0mm
TP3: 2.5V; TestPoint_THTPad_2.0x2.0mm_Drill1.0mm
U1: AT25SF081-SSHD-X; SOIC-8_3.9x4.9mm_P1.27mm
U2: ICE40HX4K-TQ144; TQFP-144_20x20mm_P0.5mm
U3: AP2112K-3.3; SOT-23-5_HandSoldering
U4: MIC5365-1.2YC5; SOT-353_SC-70-5_Handsoldering
U5: MIC5365-2.5YC5; SOT-353_SC-70-5_Handsoldering
U6: KC2520Z16.0000C15XXK; Oscillator_SMD_Kyocera_KC2520Z-4Pin_2.5x2.0mm
U7: KC3225Z3.68640C1KX00; Oscillator_SMD_Kyocera_KC2520Z-4Pin_2.5x2.0mm

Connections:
+1V2: C5.1, C6.1, C13.1, R2.1, TP2.1, U2.27 (VCC), U2.40 (VCC), U2.92 (VCC), U2.111 (VCC), U4.5 (VOUT)
+2V5: C7.1, C14.1, TP3.1, U2.108 (VPP_2V5), U5.5 (VOUT)
+3.3V: C1.1, C3.1, C10.1, C11.1, C12.1, C15.1, C16.1, JP3.3 (B), R1.1, R3.1, R7.1, R8.1, TP1.1, U1.8 (VCC), U2.72 (VCC_SPI), U3.5 (VOUT), U4.1 (VIN), U4.3 (EN), U5.1 (VIN), U5.3 (EN), U6.1 (INH), U6.4 (VCC), U7.1 (INH), U7.4 (VCC); also elsewhere on the board
+5V: C8.1, C9.1, J3.1, JP2.1 (A), JP3.1 (A), U3.1 (VIN), U3.3 (EN); also elsewhere on the board
CLK-3.6864M: U7.3 (CLK); also elsewhere on the board
CLK-16M: U6.3 (CLK); also elsewhere on the board
GND: C1.2, C2.2, C3.2, C4.2, C5.2, C6.2, C7.2, C8.2, C9.2, C10.2, C11.2, C12.2, C13.2, C14.2, C15.2, C16.2, D1.1 (K), J2.5 (GND), J2.6 (Shield), J3.2, SW1.1, U1.4 (GND), U2.5 (GND), U2.13 (GND), U2.14 (GND), U2.53 (GNDPLL0), U2.59 (GND), U2.69 (GND), U2.86 (GND), U2.103 (GND), U2.127 (GNDPLL1), U2.132 (GND), U2.140 (GND), U3.2 (GND), U4.2 (GND), U5.2 (GND), U6.2 (GND), U7.2 (GND); also elsewhere on the board
unnamed: C2.1, C4.1, R2.2, U2.54 (VCCPLL0), U2.126 (VCCPLL1)
unnamed: D1.2 (A), R7.2
unnamed: J2.1 (VBUS), JP2.2 (B)
unnamed: J2.2 (D-), R6.1
unnamed: J2.3 (D+), R4.2, R5.1
unnamed: JP1.2 (B), U2.71 (IOB_108_SS)
SCK: J1.2, U1.6 (SCK), U2.70 (IOB_107_SCK)
SDI: J1.3, U1.2 (SO/IO1), U2.68 (IOB_106_SDI)
SDO: J1.4, U1.5 (SI/IO0), U2.67 (IOB_105_SDO)
USB_DN: R6.2; also elsewhere on the board
USB_DP: R5.2; also elsewhere on the board
USB_PULLUP: R4.1; also elsewhere on the board
VBUS: JP3.2 (C); also elsewhere on the board
~CRESET: R8.2, SW1.2, U2.66 (~CRESET)
~SCS: J1.1, JP1.1 (A), U1.1 (~CS)
~SF_HOLD: R1.2, U1.7 (~HOLD/IO3); also elsewhere on the board
~SF_WP: R3.2, U1.3 (~WP/IO2); also elsewhere on the board

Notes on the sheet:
OSCILLATORS
POWER & RESET
USB
iCE40HX4K FPGA
TODO: should you include power in this connector? Most others use a 10 pin connector. Arduino uses a 6 pin one
TODO: should this jumper be here? Should it instead disconnect all pins? Something needs to be able to program the flash in circuit, but it might conflict with the FPGA. It should be possible to at least hold reset while programming SPI through the connector
SPI FLASH
POWER SUPPLY

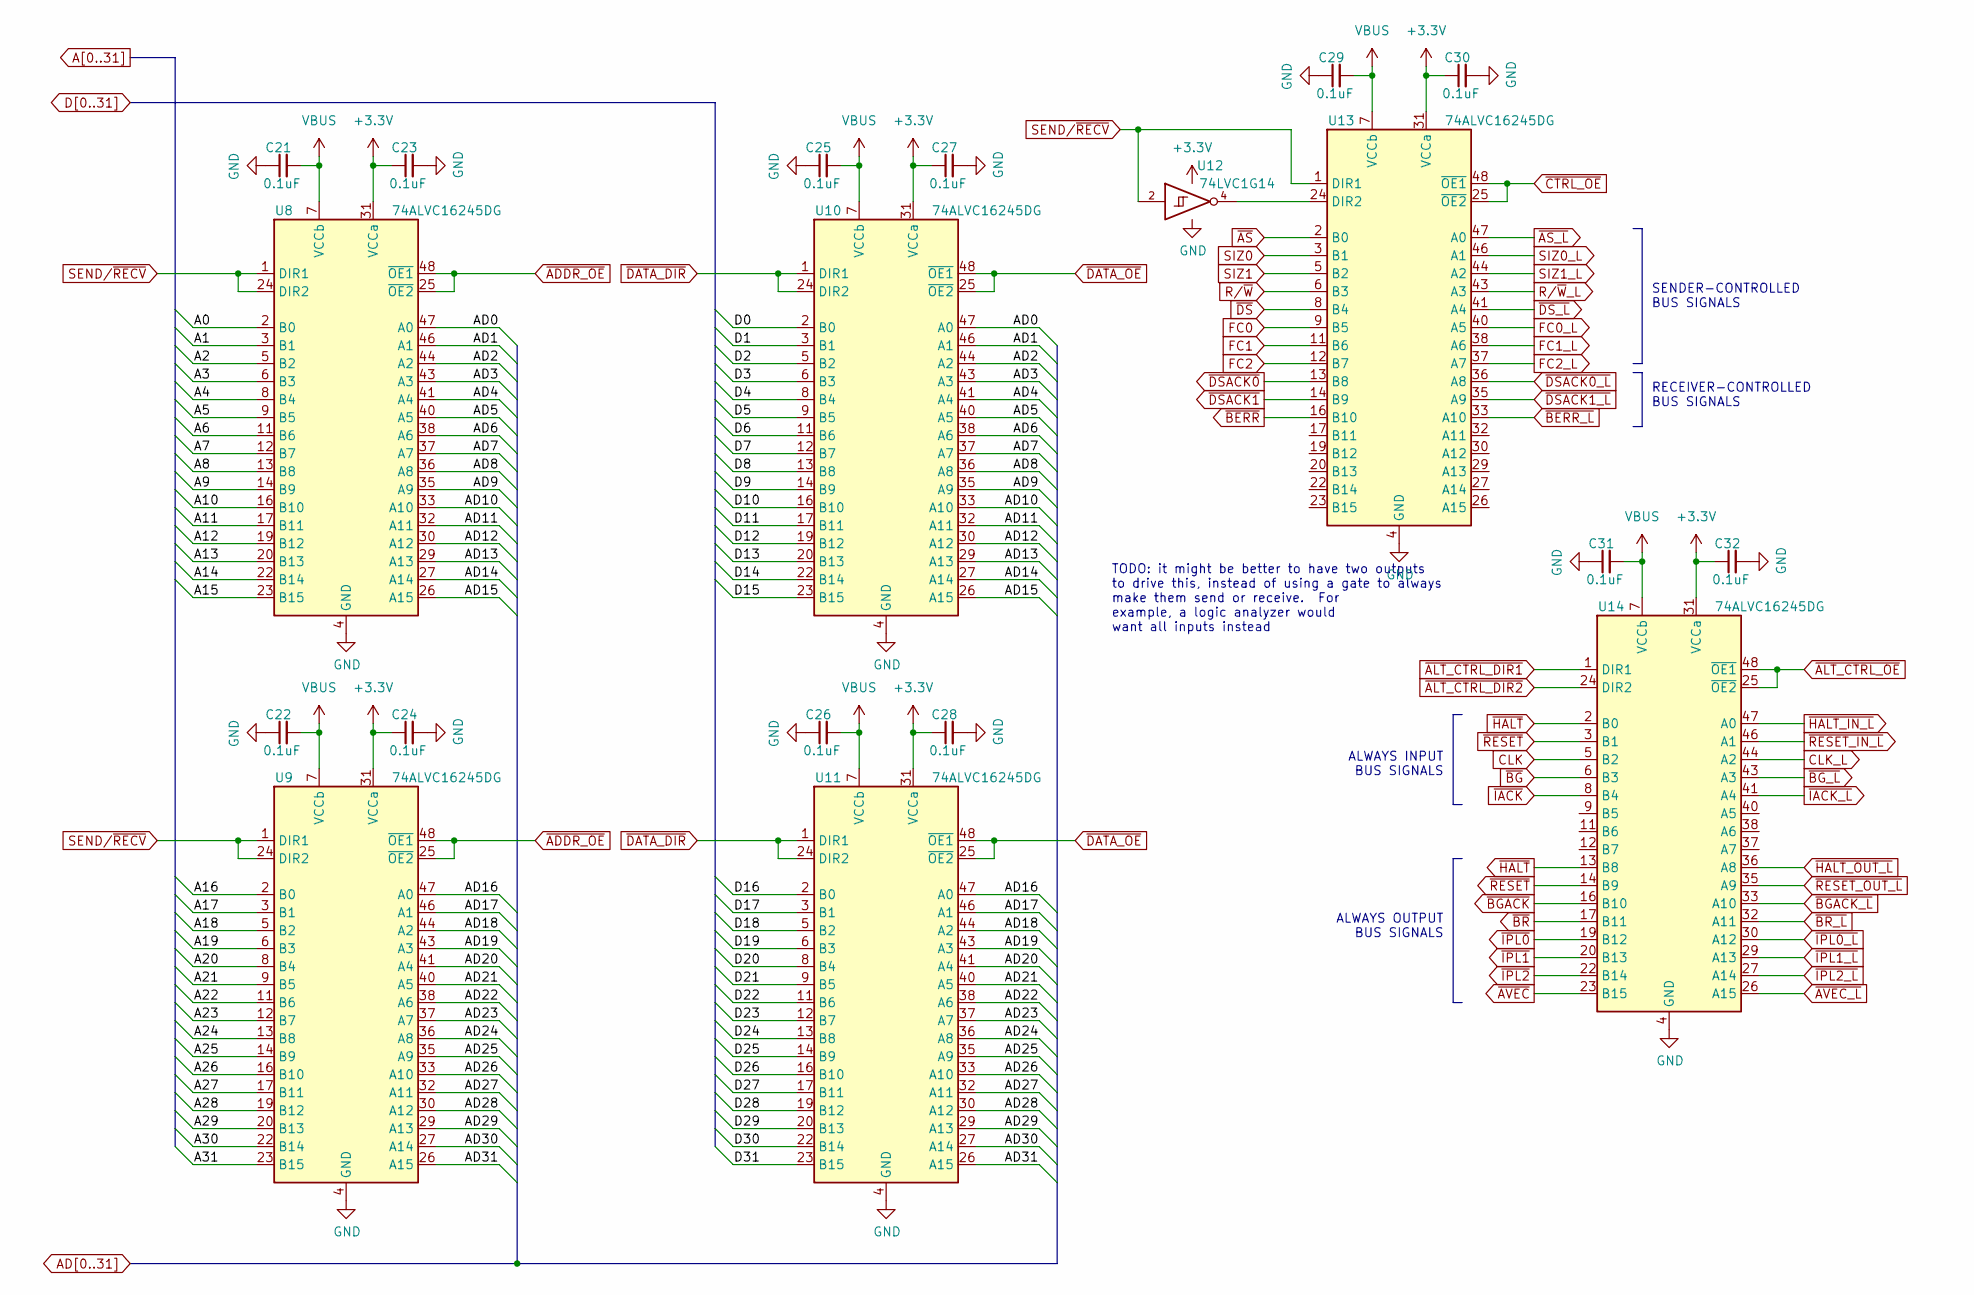
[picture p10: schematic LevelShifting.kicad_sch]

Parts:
C21, C22, C23, C24, C25, C26, C27, C28, C29, C30, C31, C32: 0.1uF; C_0805_2012Metric_Pad1.18x1.45mm_HandSolder
U8, U9, U10, U11, U13, U14: 74ALVC16245DG; TSSOP-48_6.1x12.5mm_P0.5mm
U12: 74LVC1G14; SOT-353_SC-70-5_Handsoldering

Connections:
+3.3V: C23.1, C24.1, C27.1, C28.1, C30.1, C32.1, U8.31 (VCCa), U8.42 (VCCa), U9.31 (VCCa), U9.42 (VCCa), U10.31 (VCCa), U10.42 (VCCa), U11.31 (VCCa), U11.42 (VCCa), U12.5 (VCC), U13.31 (VCCa), U13.42 (VCCa), U14.31 (VCCa), U14.42 (VCCa); also elsewhere on the board
A0: U8.2 (B0); also elsewhere on the board
A1: U8.3 (B1); also elsewhere on the board
A2: U8.5 (B2); also elsewhere on the board
A3: U8.6 (B3); also elsewhere on the board
A4: U8.8 (B4); also elsewhere on the board
A5: U8.9 (B5); also elsewhere on the board
A6: U8.11 (B6); also elsewhere on the board
A7: U8.12 (B7); also elsewhere on the board
A8: U8.13 (B8); also elsewhere on the board
A9: U8.14 (B9); also elsewhere on the board
A10: U8.16 (B10); also elsewhere on the board
A11: U8.17 (B11); also elsewhere on the board
A12: U8.19 (B12); also elsewhere on the board
A13: U8.20 (B13); also elsewhere on the board
A14: U8.22 (B14); also elsewhere on the board
A15: U8.23 (B15); also elsewhere on the board
A16: U9.2 (B0); also elsewhere on the board
A17: U9.3 (B1); also elsewhere on the board
A18: U9.5 (B2); also elsewhere on the board
A19: U9.6 (B3); also elsewhere on the board
A20: U9.8 (B4); also elsewhere on the board
A21: U9.9 (B5); also elsewhere on the board
A22: U9.11 (B6); also elsewhere on the board
A23: U9.12 (B7); also elsewhere on the board
A24: U9.13 (B8); also elsewhere on the board
A25: U9.14 (B9); also elsewhere on the board
A26: U9.16 (B10); also elsewhere on the board
A27: U9.17 (B11); also elsewhere on the board
A28: U9.19 (B12); also elsewhere on the board
A29: U9.20 (B13); also elsewhere on the board
A30: U9.22 (B14); also elsewhere on the board
A31: U9.23 (B15); also elsewhere on the board
AD0: U8.47 (A0), U10.47 (A0); also elsewhere on the board
AD1: U8.46 (A1), U10.46 (A1); also elsewhere on the board
AD2: U8.44 (A2), U10.44 (A2); also elsewhere on the board
AD3: U8.43 (A3), U10.43 (A3); also elsewhere on the board
AD4: U8.41 (A4), U10.41 (A4); also elsewhere on the board
AD5: U8.40 (A5), U10.40 (A5); also elsewhere on the board
AD6: U8.38 (A6), U10.38 (A6); also elsewhere on the board
AD7: U8.37 (A7), U10.37 (A7); also elsewhere on the board
AD8: U8.36 (A8), U10.36 (A8); also elsewhere on the board
AD9: U8.35 (A9), U10.35 (A9); also elsewhere on the board
AD10: U8.33 (A10), U10.33 (A10); also elsewhere on the board
AD11: U8.32 (A11), U10.32 (A11); also elsewhere on the board
AD12: U8.30 (A12), U10.30 (A12); also elsewhere on the board
AD13: U8.29 (A13), U10.29 (A13); also elsewhere on the board
AD14: U8.27 (A14), U10.27 (A14); also elsewhere on the board
AD15: U8.26 (A15), U10.26 (A15); also elsewhere on the board
AD16: U9.47 (A0), U11.47 (A0); also elsewhere on the board
AD17: U9.46 (A1), U11.46 (A1); also elsewhere on the board
AD18: U9.44 (A2), U11.44 (A2); also elsewhere on the board
AD19: U9.43 (A3), U11.43 (A3); also elsewhere on the board
AD20: U9.41 (A4), U11.41 (A4); also elsewhere on the board
AD21: U9.40 (A5), U11.40 (A5); also elsewhere on the board
AD22: U9.38 (A6), U11.38 (A6); also elsewhere on the board
AD23: U9.37 (A7), U11.37 (A7); also elsewhere on the board
AD24: U9.36 (A8), U11.36 (A8); also elsewhere on the board
AD25: U9.35 (A9), U11.35 (A9); also elsewhere on the board
AD26: U9.33 (A10), U11.33 (A10); also elsewhere on the board
AD27: U9.32 (A11), U11.32 (A11); also elsewhere on the board
AD28: U9.30 (A12), U11.30 (A12); also elsewhere on the board
AD29: U9.29 (A13), U11.29 (A13); also elsewhere on the board
AD30: U9.27 (A14), U11.27 (A14); also elsewhere on the board
AD31: U9.26 (A15), U11.26 (A15); also elsewhere on the board
CLK: U14.5 (B2); also elsewhere on the board
CLK_L: U14.44 (A2); also elsewhere on the board
D0: U10.2 (B0); also elsewhere on the board
D1: U10.3 (B1); also elsewhere on the board
D2: U10.5 (B2); also elsewhere on the board
D3: U10.6 (B3); also elsewhere on the board
D4: U10.8 (B4); also elsewhere on the board
D5: U10.9 (B5); also elsewhere on the board
D6: U10.11 (B6); also elsewhere on the board
D7: U10.12 (B7); also elsewhere on the board
D8: U10.13 (B8); also elsewhere on the board
D9: U10.14 (B9); also elsewhere on the board
D10: U10.16 (B10); also elsewhere on the board
D11: U10.17 (B11); also elsewhere on the board
D12: U10.19 (B12); also elsewhere on the board
D13: U10.20 (B13); also elsewhere on the board
D14: U10.22 (B14); also elsewhere on the board
D15: U10.23 (B15); also elsewhere on the board
D16: U11.2 (B0); also elsewhere on the board
D17: U11.3 (B1); also elsewhere on the board
D18: U11.5 (B2); also elsewhere on the board
D19: U11.6 (B3); also elsewhere on the board
D20: U11.8 (B4); also elsewhere on the board
D21: U11.9 (B5); also elsewhere on the board
D22: U11.11 (B6); also elsewhere on the board
D23: U11.12 (B7); also elsewhere on the board
D24: U11.13 (B8); also elsewhere on the board
D25: U11.14 (B9); also elsewhere on the board
D26: U11.16 (B10); also elsewhere on the board
D27: U11.17 (B11); also elsewhere on the board
D28: U11.19 (B12); also elsewhere on the board
D29: U11.20 (B13); also elsewhere on the board
D30: U11.22 (B14); also elsewhere on the board
D31: U11.23 (B15); also elsewhere on the board
FC0: U13.9 (B5); also elsewhere on the board
FC0_L: U13.40 (A5); also elsewhere on the board
FC1: U13.11 (B6); also elsewhere on the board
FC1_L: U13.38 (A6); also elsewhere on the board
FC2: U13.12 (B7); also elsewhere on the board
FC2_L: U13.37 (A7); also elsewhere on the board
GND: C21.1, C22.1, C23.2, C24.2, C25.1, C26.1, C27.2, C28.2, C29.1, C30.2, C31.1, C32.2, U8.4 (GND), U8.10 (GND), U8.15 (GND), U8.21 (GND), U8.28 (GND), U8.34 (GND), U8.39 (GND), U8.45 (GND), U9.4 (GND), U9.10 (GND), U9.15 (GND), U9.21 (GND), U9.28 (GND), U9.34 (GND), U9.39 (GND), U9.45 (GND), U10.4 (GND), U10.10 (GND), U10.15 (GND), U10.21 (GND), U10.28 (GND), U10.34 (GND), U10.39 (GND), U10.45 (GND), U11.4 (GND), U11.10 (GND), U11.15 (GND), U11.21 (GND), U11.28 (GND), U11.34 (GND), U11.39 (GND), U11.45 (GND), U12.3 (GND), U13.4 (GND), U13.10 (GND), U13.15 (GND), U13.21 (GND), U13.28 (GND), U13.34 (GND), U13.39 (GND), U13.45 (GND), U14.4 (GND), U14.10 (GND), U14.15 (GND), U14.21 (GND), U14.28 (GND), U14.34 (GND), U14.39 (GND), U14.45 (GND); also elsewhere on the board
unnamed: U12.4, U13.24 (DIR2)
R/~W: U13.6 (B3); also elsewhere on the board
R/~W_L: U13.43 (A3); also elsewhere on the board
SEND/~RECV: U8.1 (DIR1), U8.24 (DIR2), U9.1 (DIR1), U9.24 (DIR2), U12.2, U13.1 (DIR1); also elsewhere on the board
SIZ0: U13.3 (B1); also elsewhere on the board
SIZ0_L: U13.46 (A1); also elsewhere on the board
SIZ1: U13.5 (B2); also elsewhere on the board
SIZ1_L: U13.44 (A2); also elsewhere on the board
VBUS: C21.2, C22.2, C25.2, C26.2, C29.2, C31.2, U8.7 (VCCb), U8.18 (VCCb), U9.7 (VCCb), U9.18 (VCCb), U10.7 (VCCb), U10.18 (VCCb), U11.7 (VCCb), U11.18 (VCCb), U13.7 (VCCb), U13.18 (VCCb), U14.7 (VCCb), U14.18 (VCCb); also elsewhere on the board
~ADDR_OE: U8.25 (~OE2), U8.48 (~OE1), U9.25 (~OE2), U9.48 (~OE1); also elsewhere on the board
~ALT_CTRL_DIR1: U14.1 (DIR1); also elsewhere on the board
~ALT_CTRL_DIR2: U14.24 (DIR2); also elsewhere on the board
~ALT_CTRL_OE: U14.25 (~OE2), U14.48 (~OE1); also elsewhere on the board
~AS_L: U13.47 (A0); also elsewhere on the board
~AS: U13.2 (B0); also elsewhere on the board
~AVEC_L: U14.26 (A15); also elsewhere on the board
~AVEC: U14.23 (B15); also elsewhere on the board
~BERR_L: U13.33 (A10); also elsewhere on the board
~BERR: U13.16 (B10); also elsewhere on the board
~BGACK_L: U14.33 (A10); also elsewhere on the board
~BGACK: U14.16 (B10); also elsewhere on the board
~BG_L: U14.43 (A3); also elsewhere on the board
~BG: U14.6 (B3); also elsewhere on the board
~BR_L: U14.32 (A11); also elsewhere on the board
~BR: U14.17 (B11); also elsewhere on the board
~CTRL_OE: U13.25 (~OE2), U13.48 (~OE1); also elsewhere on the board
~DATA_DIR: U10.1 (DIR1), U10.24 (DIR2), U11.1 (DIR1), U11.24 (DIR2); also elsewhere on the board
~DATA_OE: U10.25 (~OE2), U10.48 (~OE1), U11.25 (~OE2), U11.48 (~OE1); also elsewhere on the board
~DSACK0_L: U13.36 (A8); also elsewhere on the board
~DSACK0: U13.13 (B8); also elsewhere on the board
~DSACK1_L: U13.35 (A9); also elsewhere on the board
~DSACK1: U13.14 (B9); also elsewhere on the board
~DS_L: U13.41 (A4); also elsewhere on the board
~DS: U13.8 (B4); also elsewhere on the board
~HALT_IN_L: U14.47 (A0); also elsewhere on the board
~HALT_OUT_L: U14.36 (A8); also elsewhere on the board
~HALT: U14.2 (B0), U14.13 (B8); also elsewhere on the board
~IACK_L: U14.41 (A4); also elsewhere on the board
~IACK: U14.8 (B4); also elsewhere on the board
~IPL0_L: U14.30 (A12); also elsewhere on the board
~IPL0: U14.19 (B12); also elsewhere on the board
~IPL1_L: U14.29 (A13); also elsewhere on the board
~IPL1: U14.20 (B13); also elsewhere on the board
~IPL2_L: U14.27 (A14); also elsewhere on the board
~IPL2: U14.22 (B14); also elsewhere on the board
~RESET_IN_L: U14.46 (A1); also elsewhere on the board
~RESET_OUT_L: U14.35 (A9); also elsewhere on the board
~RESET: U14.3 (B1), U14.14 (B9); also elsewhere on the board

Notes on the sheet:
TODO: it might be better to have two outputs to drive this, instead of using a gate to always make them send or receive. For example, a logic analyzer would want all inputs instead
SENDER-CONTROLLED BUS SIGNALS
ALWAYS INPUT BUS SIGNALS
ALWAYS OUTPUT BUS SIGNALS
RECEIVER-CONTROLLED BUS SIGNALS

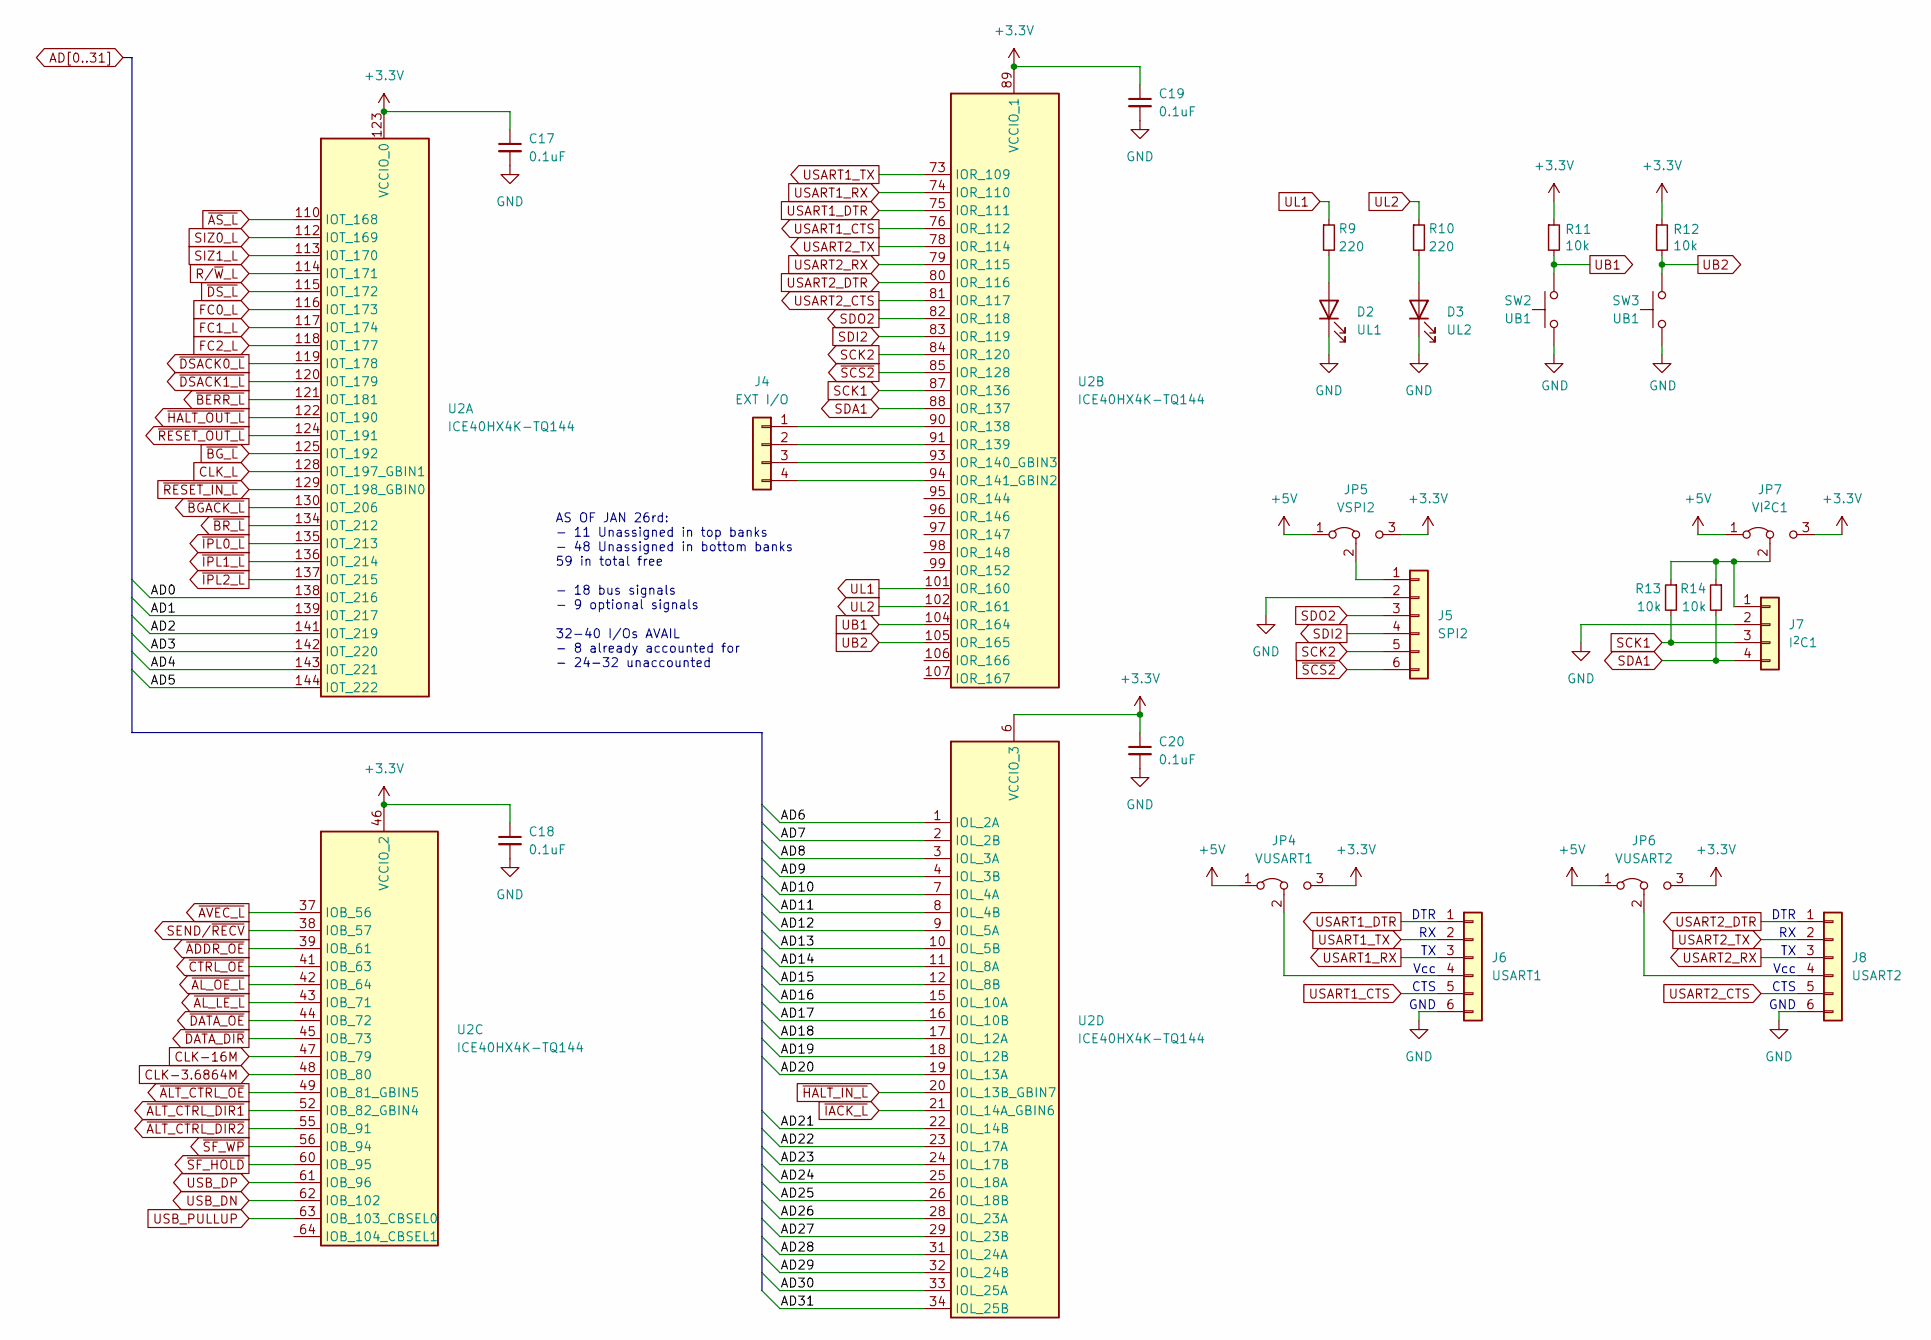
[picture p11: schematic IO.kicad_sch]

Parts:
C17, C18, C19, C20: 0.1uF; C_0805_2012Metric_Pad1.18x1.45mm_HandSolder
D2: UL1
D3: UL2
J4: EXT I/O; PinHeader_1x04_P2.54mm_Vertical
J5: SPI2; PinHeader_1x06_P2.54mm_Vertical
J6: USART1; PinHeader_1x06_P2.54mm_Vertical
J7: I^{2}C1; PinHeader_1x04_P2.54mm_Vertical
J8: USART2; PinHeader_1x06_P2.54mm_Vertical
JP4: VUSART1; PinHeader_1x03_P2.54mm_Vertical
JP5: VSPI2; PinHeader_1x03_P2.54mm_Vertical
JP6: VUSART2; PinHeader_1x03_P2.54mm_Vertical
JP7: VI^{2}C1; PinHeader_1x03_P2.54mm_Vertical
R9, R10: 220; R_Axial_DIN0204_L3.6mm_D1.6mm_P5.08mm_Horizontal
R11, R12, R13, R14: 10k; R_Axial_DIN0204_L3.6mm_D1.6mm_P5.08mm_Horizontal
SW2, SW3: UB1; SW_PUSH_6mm
U2: ICE40HX4K-TQ144; TQFP-144_20x20mm_P0.5mm

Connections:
+3.3V: C17.1, C18.1, C19.1, C20.1, JP4.3 (B), JP5.3 (B), JP6.3 (B), JP7.3 (B), R11.1, R12.1, U2.6 (VCCIO_3), U2.30 (VCCIO_3), U2.46 (VCCIO_2), U2.57 (VCCIO_2), U2.89 (VCCIO_1), U2.100 (VCCIO_1), U2.123 (VCCIO_0), U2.131 (VCCIO_0); also elsewhere on the board
+5V: JP4.1 (A), JP5.1 (A), JP6.1 (A), JP7.1 (A); also elsewhere on the board
AD0: U2.138 (IOT_216); also elsewhere on the board
AD1: U2.139 (IOT_217); also elsewhere on the board
AD2: U2.141 (IOT_219); also elsewhere on the board
AD3: U2.142 (IOT_220); also elsewhere on the board
AD4: U2.143 (IOT_221); also elsewhere on the board
AD5: U2.144 (IOT_222); also elsewhere on the board
AD6: U2.1 (IOL_2A); also elsewhere on the board
AD7: U2.2 (IOL_2B); also elsewhere on the board
AD8: U2.3 (IOL_3A); also elsewhere on the board
AD9: U2.4 (IOL_3B); also elsewhere on the board
AD10: U2.7 (IOL_4A); also elsewhere on the board
AD11: U2.8 (IOL_4B); also elsewhere on the board
AD12: U2.9 (IOL_5A); also elsewhere on the board
AD13: U2.10 (IOL_5B); also elsewhere on the board
AD14: U2.11 (IOL_8A); also elsewhere on the board
AD15: U2.12 (IOL_8B); also elsewhere on the board
AD16: U2.15 (IOL_10A); also elsewhere on the board
AD17: U2.16 (IOL_10B); also elsewhere on the board
AD18: U2.17 (IOL_12A); also elsewhere on the board
AD19: U2.18 (IOL_12B); also elsewhere on the board
AD20: U2.19 (IOL_13A); also elsewhere on the board
AD21: U2.22 (IOL_14B); also elsewhere on the board
AD22: U2.23 (IOL_17A); also elsewhere on the board
AD23: U2.24 (IOL_17B); also elsewhere on the board
AD24: U2.25 (IOL_18A); also elsewhere on the board
AD25: U2.26 (IOL_18B); also elsewhere on the board
AD26: U2.28 (IOL_23A); also elsewhere on the board
AD27: U2.29 (IOL_23B); also elsewhere on the board
AD28: U2.31 (IOL_24A); also elsewhere on the board
AD29: U2.32 (IOL_24B); also elsewhere on the board
AD30: U2.33 (IOL_25A); also elsewhere on the board
AD31: U2.34 (IOL_25B); also elsewhere on the board
CLK-3.6864M: U2.48 (IOB_80); also elsewhere on the board
CLK-16M: U2.47 (IOB_79); also elsewhere on the board
CLK_L: U2.128 (IOT_197_GBIN1); also elsewhere on the board
FC0_L: U2.116 (IOT_173); also elsewhere on the board
FC1_L: U2.117 (IOT_174); also elsewhere on the board
FC2_L: U2.118 (IOT_177); also elsewhere on the board
GND: C17.2, C18.2, C19.2, C20.2, D2.1 (K), D3.1 (K), J5.2, J6.6, J7.2, J8.6, SW2.1, SW3.1; also elsewhere on the board
unnamed: D2.2 (A), R9.2
unnamed: D3.2 (A), R10.2
unnamed: J4.1, U2.90 (IOR_138)
unnamed: J4.2, U2.91 (IOR_139)
unnamed: J4.3, U2.93 (IOR_140_GBIN3)
unnamed: J4.4, U2.94 (IOR_141_GBIN2)
unnamed: J5.1, JP5.2 (C)
unnamed: J6.4, JP4.2 (C)
unnamed: J7.1, JP7.2 (C), R13.1, R14.1
unnamed: J8.4, JP6.2 (C)
R/~W_L: U2.114 (IOT_171); also elsewhere on the board
SCK1: J7.3, R13.2, U2.87 (IOR_136)
SCK2: J5.5, U2.84 (IOR_120)
SDA1: J7.4, R14.2, U2.88 (IOR_137)
SDI2: J5.4, U2.83 (IOR_119)
SDO2: J5.3, U2.82 (IOR_118)
SEND/~RECV: U2.38 (IOB_57); also elsewhere on the board
SIZ0_L: U2.112 (IOT_169); also elsewhere on the board
SIZ1_L: U2.113 (IOT_170); also elsewhere on the board
UB1: R11.2, SW2.2, U2.104 (IOR_164)
UB2: R12.2, SW3.2, U2.105 (IOR_165)
UL1: R9.1, U2.101 (IOR_160)
UL2: R10.1, U2.102 (IOR_161)
USART1_CTS: J6.5, U2.76 (IOR_112)
USART1_DTR: J6.1, U2.75 (IOR_111)
USART1_RX: J6.3, U2.74 (IOR_110)
USART1_TX: J6.2, U2.73 (IOR_109)
USART2_CTS: J8.5, U2.81 (IOR_117)
USART2_DTR: J8.1, U2.80 (IOR_116)
USART2_RX: J8.3, U2.79 (IOR_115)
USART2_TX: J8.2, U2.78 (IOR_114)
USB_DN: U2.62 (IOB_102); also elsewhere on the board
USB_DP: U2.61 (IOB_96); also elsewhere on the board
USB_PULLUP: U2.63 (IOB_103_CBSEL0); also elsewhere on the board
~ADDR_OE: U2.39 (IOB_61); also elsewhere on the board
~ALT_CTRL_DIR1: U2.52 (IOB_82_GBIN4); also elsewhere on the board
~ALT_CTRL_DIR2: U2.55 (IOB_91); also elsewhere on the board
~ALT_CTRL_OE: U2.49 (IOB_81_GBIN5); also elsewhere on the board
~AL_LE_L: U2.43 (IOB_71); also elsewhere on the board
~AL_OE_L: U2.42 (IOB_64); also elsewhere on the board
~AS_L: U2.110 (IOT_168); also elsewhere on the board
~AVEC_L: U2.37 (IOB_56); also elsewhere on the board
~BERR_L: U2.121 (IOT_181); also elsewhere on the board
~BGACK_L: U2.130 (IOT_206); also elsewhere on the board
~BG_L: U2.125 (IOT_192); also elsewhere on the board
~BR_L: U2.134 (IOT_212); also elsewhere on the board
~CTRL_OE: U2.41 (IOB_63); also elsewhere on the board
~DATA_DIR: U2.45 (IOB_73); also elsewhere on the board
~DATA_OE: U2.44 (IOB_72); also elsewhere on the board
~DSACK0_L: U2.119 (IOT_178); also elsewhere on the board
~DSACK1_L: U2.120 (IOT_179); also elsewhere on the board
~DS_L: U2.115 (IOT_172); also elsewhere on the board
~HALT_IN_L: U2.20 (IOL_13B_GBIN7); also elsewhere on the board
~HALT_OUT_L: U2.122 (IOT_190); also elsewhere on the board
~IACK_L: U2.21 (IOL_14A_GBIN6); also elsewhere on the board
~IPL0_L: U2.135 (IOT_213); also elsewhere on the board
~IPL1_L: U2.136 (IOT_214); also elsewhere on the board
~IPL2_L: U2.137 (IOT_215); also elsewhere on the board
~RESET_IN_L: U2.129 (IOT_198_GBIN0); also elsewhere on the board
~RESET_OUT_L: U2.124 (IOT_191); also elsewhere on the board
~SCS2: J5.6, U2.85 (IOR_128)
~SF_HOLD: U2.60 (IOB_95); also elsewhere on the board
~SF_WP: U2.56 (IOB_94); also elsewhere on the board

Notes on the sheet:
DTR
GND
CTS
Vcc
AS OF JAN 26rd: - 11 Unassigned in top banks - 48 Unassigned in bottom banks 59 in total free - 18 bus signals - 9 optional signals 32-40 I/Os AVAIL - 8 already accounted for - 24-32 unaccounted

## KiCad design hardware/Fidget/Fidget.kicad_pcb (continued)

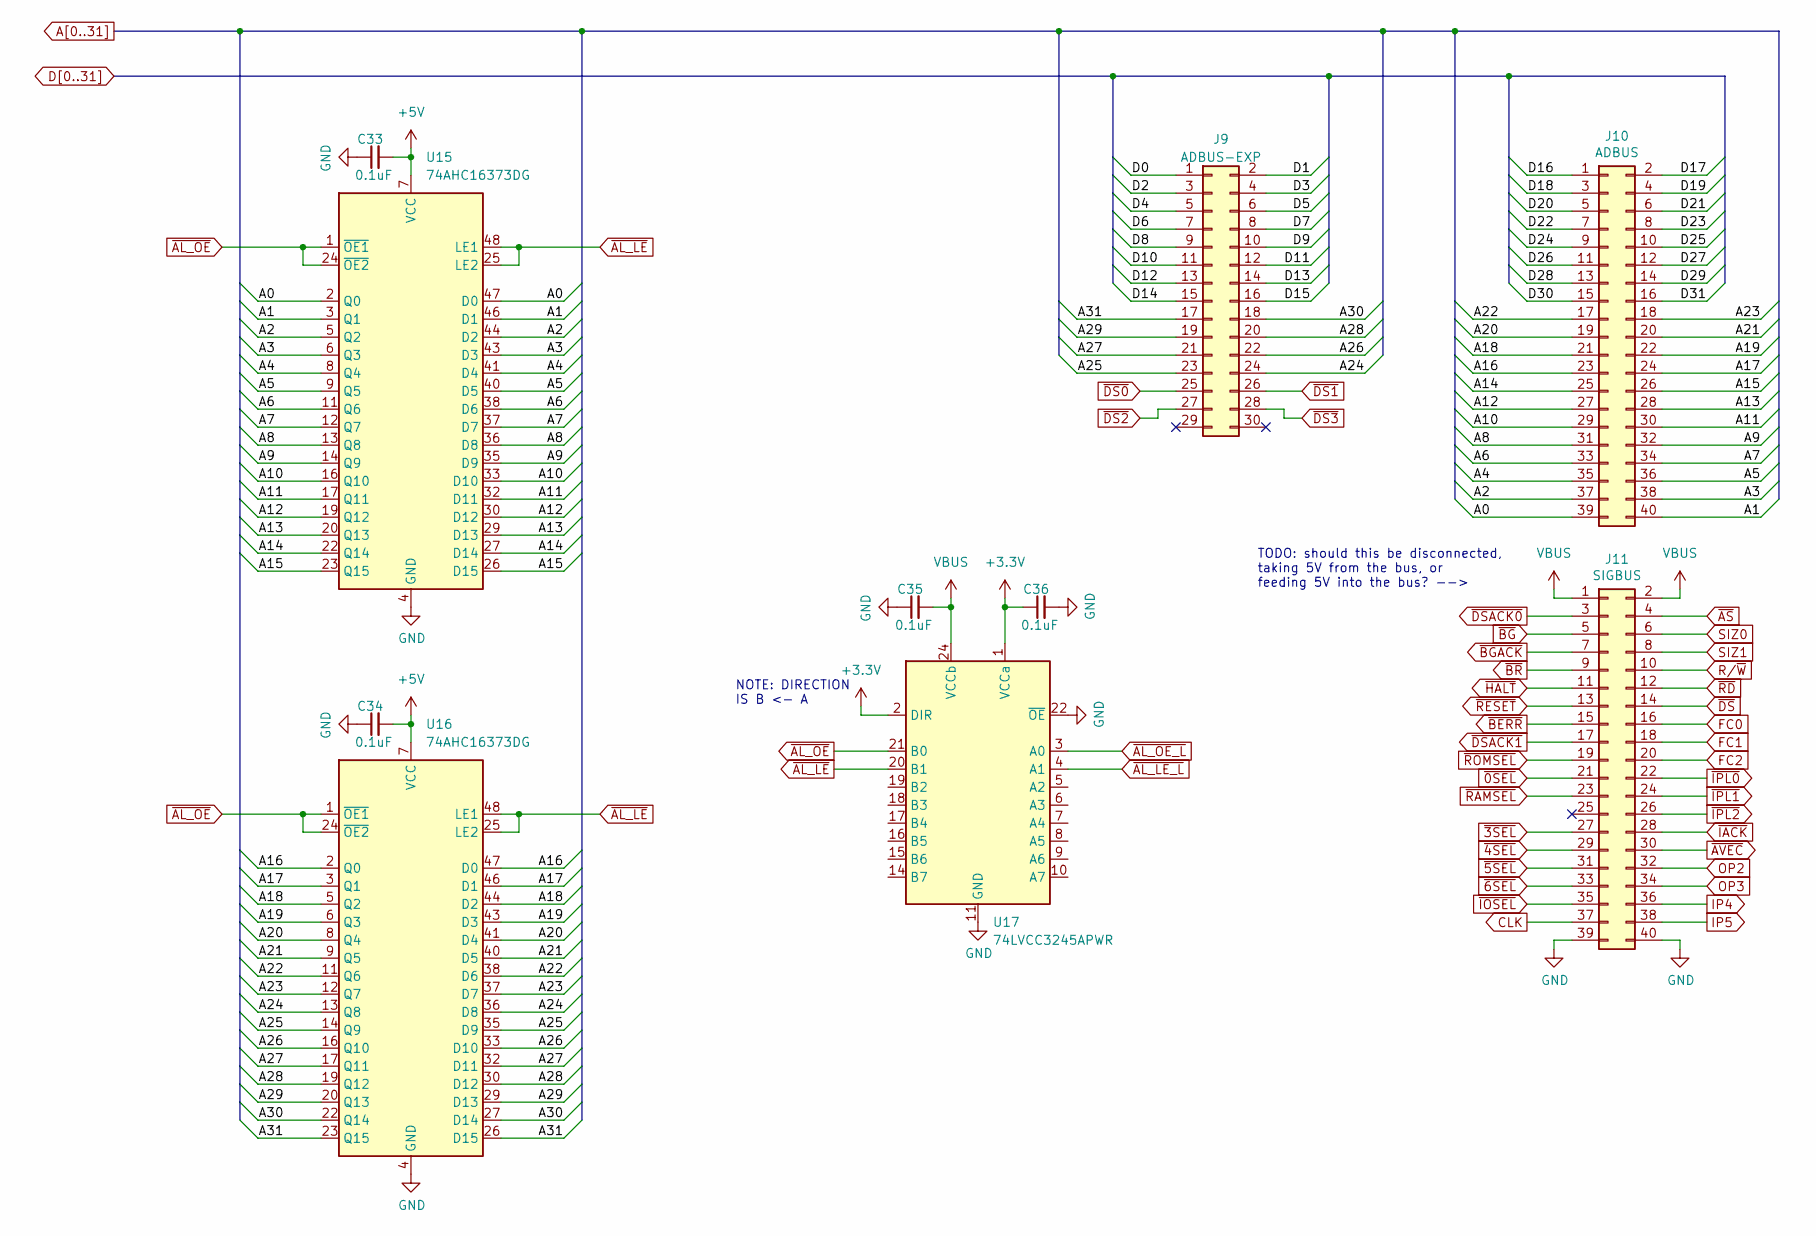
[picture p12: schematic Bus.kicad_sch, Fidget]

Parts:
C33, C34, C35, C36: 0.1uF; C_0805_2012Metric_Pad1.18x1.45mm_HandSolder
J9: ADBUS-EXP; PinHeader_2x15_P2.54mm_Vertical
J10: ADBUS; PinHeader_2x20_P2.54mm_Vertical
J11: SIGBUS; PinHeader_2x20_P2.54mm_Vertical
U15, U16: 74AHC16373DG; TSSOP-48_6.1x12.5mm_P0.5mm
U17: 74LVCC3245APWR; TSSOP-24_4.4x7.8mm_P0.65mm

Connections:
+3.3V: C36.1, U17.1 (VCCa), U17.2 (DIR); also elsewhere on the board
+5V: C33.2, C34.2, U15.7 (VCC), U15.18 (VCC), U15.31 (VCC), U15.42 (VCC), U16.7 (VCC), U16.18 (VCC), U16.31 (VCC), U16.42 (VCC); also elsewhere on the board
A0: J10.39, U15.2 (Q0), U15.47 (D0); also elsewhere on the board
A1: J10.40, U15.3 (Q1), U15.46 (D1); also elsewhere on the board
A2: J10.37, U15.5 (Q2), U15.44 (D2); also elsewhere on the board
A3: J10.38, U15.6 (Q3), U15.43 (D3); also elsewhere on the board
A4: J10.35, U15.8 (Q4), U15.41 (D4); also elsewhere on the board
A5: J10.36, U15.9 (Q5), U15.40 (D5); also elsewhere on the board
A6: J10.33, U15.11 (Q6), U15.38 (D6); also elsewhere on the board
A7: J10.34, U15.12 (Q7), U15.37 (D7); also elsewhere on the board
A8: J10.31, U15.13 (Q8), U15.36 (D8); also elsewhere on the board
A9: J10.32, U15.14 (Q9), U15.35 (D9); also elsewhere on the board
A10: J10.29, U15.16 (Q10), U15.33 (D10); also elsewhere on the board
A11: J10.30, U15.17 (Q11), U15.32 (D11); also elsewhere on the board
A12: J10.27, U15.19 (Q12), U15.30 (D12); also elsewhere on the board
A13: J10.28, U15.20 (Q13), U15.29 (D13); also elsewhere on the board
A14: J10.25, U15.22 (Q14), U15.27 (D14); also elsewhere on the board
A15: J10.26, U15.23 (Q15), U15.26 (D15); also elsewhere on the board
A16: J10.23, U16.2 (Q0), U16.47 (D0); also elsewhere on the board
A17: J10.24, U16.3 (Q1), U16.46 (D1); also elsewhere on the board
A18: J10.21, U16.5 (Q2), U16.44 (D2); also elsewhere on the board
A19: J10.22, U16.6 (Q3), U16.43 (D3); also elsewhere on the board
A20: J10.19, U16.8 (Q4), U16.41 (D4); also elsewhere on the board
A21: J10.20, U16.9 (Q5), U16.40 (D5); also elsewhere on the board
A22: J10.17, U16.11 (Q6), U16.38 (D6); also elsewhere on the board
A23: J10.18, U16.12 (Q7), U16.37 (D7); also elsewhere on the board
A24: J9.24, U16.13 (Q8), U16.36 (D8); also elsewhere on the board
A25: J9.23, U16.14 (Q9), U16.35 (D9); also elsewhere on the board
A26: J9.22, U16.16 (Q10), U16.33 (D10); also elsewhere on the board
A27: J9.21, U16.17 (Q11), U16.32 (D11); also elsewhere on the board
A28: J9.20, U16.19 (Q12), U16.30 (D12); also elsewhere on the board
A29: J9.19, U16.20 (Q13), U16.29 (D13); also elsewhere on the board
A30: J9.18, U16.22 (Q14), U16.27 (D14); also elsewhere on the board
A31: J9.17, U16.23 (Q15), U16.26 (D15); also elsewhere on the board
CLK: J11.37; also elsewhere on the board
D0: J9.1; also elsewhere on the board
D1: J9.2; also elsewhere on the board
D2: J9.3; also elsewhere on the board
D3: J9.4; also elsewhere on the board
D4: J9.5; also elsewhere on the board
D5: J9.6; also elsewhere on the board
D6: J9.7; also elsewhere on the board
D7: J9.8; also elsewhere on the board
D8: J9.9; also elsewhere on the board
D9: J9.10; also elsewhere on the board
D10: J9.11; also elsewhere on the board
D11: J9.12; also elsewhere on the board
D12: J9.13; also elsewhere on the board
D13: J9.14; also elsewhere on the board
D14: J9.15; also elsewhere on the board
D15: J9.16; also elsewhere on the board
D16: J10.1; also elsewhere on the board
D17: J10.2; also elsewhere on the board
D18: J10.3; also elsewhere on the board
D19: J10.4; also elsewhere on the board
D20: J10.5; also elsewhere on the board
D21: J10.6; also elsewhere on the board
D22: J10.7; also elsewhere on the board
D23: J10.8; also elsewhere on the board
D24: J10.9; also elsewhere on the board
D25: J10.10; also elsewhere on the board
D26: J10.11; also elsewhere on the board
D27: J10.12; also elsewhere on the board
D28: J10.13; also elsewhere on the board
D29: J10.14; also elsewhere on the board
D30: J10.15; also elsewhere on the board
D31: J10.16; also elsewhere on the board
FC0: J11.16; also elsewhere on the board
FC1: J11.18; also elsewhere on the board
FC2: J11.20; also elsewhere on the board
GND: C33.1, C34.1, C35.1, C36.2, J11.39, J11.40, U15.4 (GND), U15.10 (GND), U15.15 (GND), U15.21 (GND), U15.28 (GND), U15.34 (GND), U15.39 (GND), U15.45 (GND), U16.4 (GND), U16.10 (GND), U16.15 (GND), U16.21 (GND), U16.28 (GND), U16.34 (GND), U16.39 (GND), U16.45 (GND), U17.11 (GND), U17.12 (GND), U17.13 (GND), U17.22 (~OE); also elsewhere on the board
IP4: J11.36
IP5: J11.38
OP2: J11.32
OP3: J11.34
R/~W: J11.10; also elsewhere on the board
SIZ0: J11.6; also elsewhere on the board
SIZ1: J11.8; also elsewhere on the board
VBUS: C35.2, J11.1, J11.2, U17.24 (VCCb); also elsewhere on the board
~0SEL: J11.21
~3SEL: J11.27
~4SEL: J11.29
~5SEL: J11.31
~6SEL: J11.33
~AL_LE_L: U17.4 (A1); also elsewhere on the board
~AL_LE: U15.25 (LE2), U15.48 (LE1), U16.25 (LE2), U16.48 (LE1), U17.20 (B1)
~AL_OE_L: U17.3 (A0); also elsewhere on the board
~AL_OE: U15.1 (~OE1), U15.24 (~OE2), U16.1 (~OE1), U16.24 (~OE2), U17.21 (B0)
~AS: J11.4; also elsewhere on the board
~AVEC: J11.30; also elsewhere on the board
~BERR: J11.15; also elsewhere on the board
~BGACK: J11.7; also elsewhere on the board
~BG: J11.5; also elsewhere on the board
~BR: J11.9; also elsewhere on the board
~DS0: J9.25
~DS1: J9.26
~DS2: J9.27
~DS3: J9.28
~DSACK0: J11.3; also elsewhere on the board
~DSACK1: J11.17; also elsewhere on the board
~DS: J11.14; also elsewhere on the board
~HALT: J11.11; also elsewhere on the board
~IACK: J11.28; also elsewhere on the board
~IOSEL: J11.35
~IPL0: J11.22; also elsewhere on the board
~IPL1: J11.24; also elsewhere on the board
~IPL2: J11.26; also elsewhere on the board
~RAMSEL: J11.23
~RD: J11.12
~RESET: J11.13; also elsewhere on the board
~ROMSEL: J11.19

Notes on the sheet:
NOTE: DIRECTION IS B <- A
TODO: should this be disconnected, taking 5V from the bus, or feeding 5V into the bus? -->

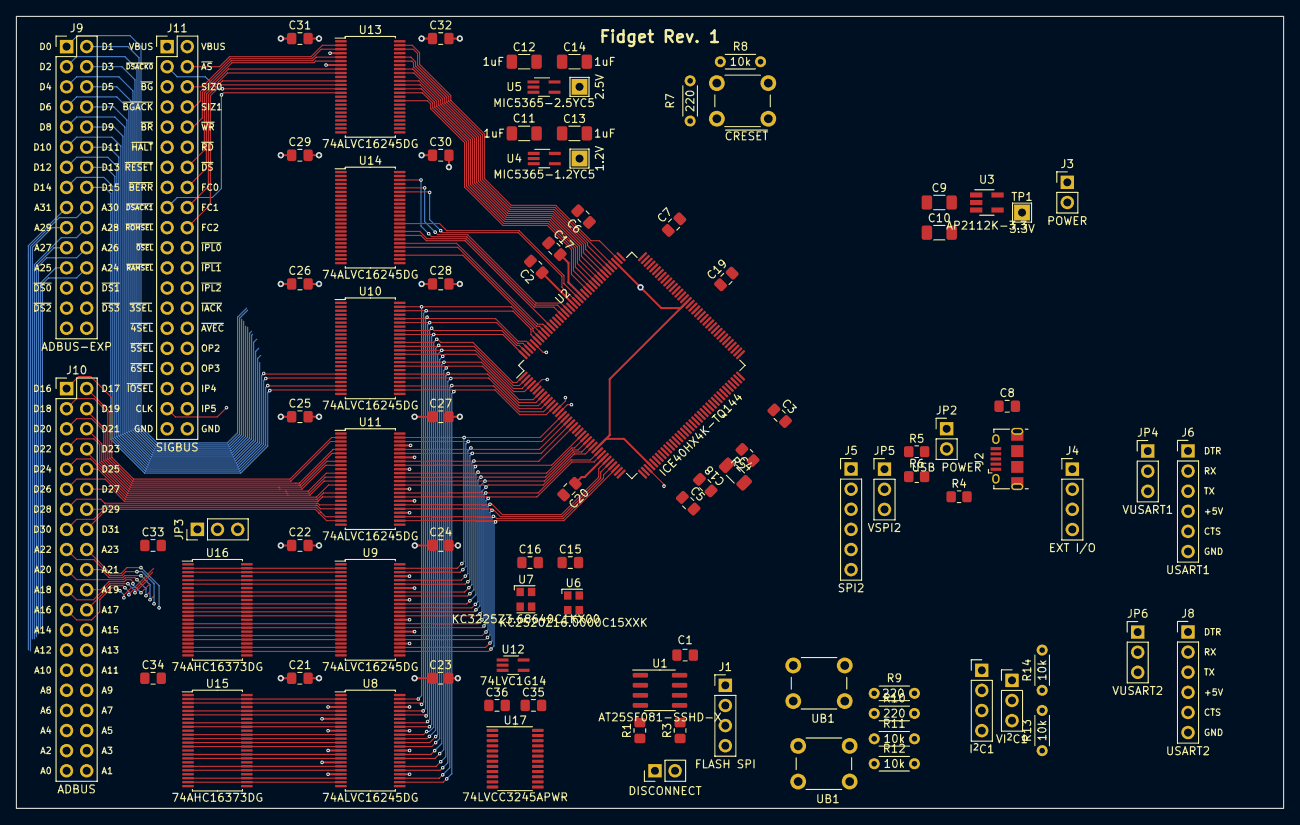
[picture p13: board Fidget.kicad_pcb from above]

Board: 4 copper layers, 160.0 x 100.0 mm, 91 parts (0 on the bottom side), 204 nets.

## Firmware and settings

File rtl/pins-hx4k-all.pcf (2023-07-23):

#
# FPGA:		Lattice iCE40 HX4K
# Package:	TQ-144
#
set_io -nowarn pin_ad[6]		1	# IOL_2A
set_io -nowarn pin_ad[7]		2       # IOL_2B
set_io -nowarn pin_ad[8]		3       # IOL_3A
set_io -nowarn pin_ad[9]		4       # IOL_3B
set_io -nowarn pin_ad[10]		7       # IOL_4A
set_io -nowarn pin_ad[11]		8       # IOL_4B
set_io -nowarn pin_ad[12]		9       # IOL_5A
set_io -nowarn pin_ad[13]		10      # IOL_5B
set_io -nowarn pin_ad[14]		11      # IOL_8A
set_io -nowarn pin_ad[15]		12      # IOL_8B
set_io -nowarn pin_ad[16]		15      # IOL_10A
set_io -nowarn pin_ad[17]		16      # IOL_10B
set_io -nowarn pin_ad[18]		17      # IOL_12A
set_io -nowarn pin_ad[19]		18      # IOL_12B
set_io -nowarn pin_ad[20]		19      # IOL_13A
set_io -nowarn pin_halt_in		20      # IOL_13B_GBIN7
set_io -nowarn pin_iack			21      # IOL_14A_GBIN6
set_io -nowarn pin_ad[21]		22      # IOL_14B
set_io -nowarn pin_ad[22]      		23      # IOL_17A
set_io -nowarn pin_ad[23]      		24      # IOL_17B
set_io -nowarn pin_ad[24]		25      # IOL_18A
set_io -nowarn pin_ad[25]		26      # IOL_18B
set_io -nowarn pin_ad[26]		28      # IOL_23A
set_io -nowarn pin_ad[27]		29      # IOL_23B
set_io -nowarn pin_ad[28]      		31      # IOL_24A
set_io -nowarn pin_ad[29]      		32      # IOL_24B
set_io -nowarn pin_ad[30]		33      # IOL_25A
set_io -nowarn pin_ad[31]		34      # IOL_25B
set_io -nowarn pin_avec			37      # IOB_56
set_io -nowarn pin_ctrl_oe     		38      # IOB_57
set_io -nowarn pin_alt_ctrl_oe 		39      # IOB_61
set_io -nowarn pin_alt_ctrl_dir1	41      # IOB_63
set_io -nowarn pin_alt_ctrl_dir2	42      # IOB_64
set_io -nowarn pin_data_dir		43      # IOB_71
set_io -nowarn pin_data_oe		44      # IOB_72
set_io -nowarn pin_send_receive		45      # IOB_73
set_io -nowarn pin_clk_16M		47      # IOB_79
set_io -nowarn pin_clk_3_6864M		48      # IOB_80
set_io -nowarn pin_addr_oe		49      # IOB_81_GBIN5
set_io -nowarn pin_al_oe		52      # IOB_82_GBIN4
set_io -nowarn pin_al_le		55      # IOB_91
set_io -nowarn pin_ul1			56      # IOB_94
set_io -nowarn pin_ul2			60      # IOB_95
set_io -nowarn pin_ul3			61      # IOB_96
set_io -nowarn pin_ul4			62      # IOB_102
set_io -nowarn pin_ub1			63      # IOB_103_CBSEL0
set_io -nowarn pin_ub2			64      # IOB_104_CBSEL1
set_io -nowarn pin_sdo			67      # IOB_105_SDO
set_io -nowarn pin_sdi			68      # IOB_106_SDI
set_io -nowarn pin_sck			70      # IOB_107_SCK
set_io -nowarn pin_scs			71      # IOB_108_SS
set_io -nowarn pin_sf_wp		73      # IOR_109
set_io -nowarn pin_sf_hold		74      # IOR_110
set_io -nowarn pin_sdo2			75      # IOR_111
set_io -nowarn pin_sdi2			76      # IOR_112
set_io -nowarn pin_sck2			78      # IOR_114
set_io -nowarn pin_scs2			79      # IOR_115
set_io -nowarn pin_sck1			80      # IOR_116
set_io -nowarn pin_sda1			81      # IOR_117
set_io -nowarn pin_usb_dn		82      # IOR_118
set_io -nowarn pin_usb_dp		83      # IOR_119
set_io -nowarn pin_usb_pullup		84      # IOR_120
set_io -nowarn pin_usart1_tx		85      # IOR_128
set_io -nowarn pin_usart1_rx		87      # IOR_136
set_io -nowarn pin_usart1_cts		88      # IOR_137, DTR on Rev1 (Input into FPGA)
set_io -nowarn pin_usart1_rts		90      # IOR_138, CTS on Rev1 (Output from FPGA)
set_io -nowarn pin_usart2_tx		91      # IOR_139
set_io -nowarn pin_usart2_rx		93      # IOR_140_GBIN3
set_io -nowarn pin_usart2_cts		94      # IOR_141_GBIN2, DTR on Rev1 (Input into FPGA)
set_io -nowarn pin_usart2_rts		95      # IOR_144, CTS on Rev1 (Output from FPGA)
set_io -nowarn pin_ext_1		96      # IOR_146
set_io -nowarn pin_ext_2		97      # IOR_147
set_io -nowarn pin_ext_3		98      # IOR_148
set_io -nowarn pin_ext_4		99      # IOR_152
set_io -nowarn pin_ext_5		101     # IOR_160
set_io -nowarn pin_ext_6		102     # IOR_161
set_io -nowarn pin_ext_7     		104     # IOR_164
set_io -nowarn pin_ext_8     		105     # IOR_165
set_io -nowarn pin_ext_9     		106     # IOR_166
set_io -nowarn pin_ext_10     		107     # IOR_167
set_io -nowarn pin_as			110     # IOT_168
set_io -nowarn pin_siz0			112     # IOT_169
set_io -nowarn pin_siz1			113     # IOT_170
set_io -nowarn pin_rw			114     # IOT_171
set_io -nowarn pin_ds			115     # IOT_172
set_io -nowarn pin_fc0			116     # IOT_173
set_io -nowarn pin_fc1			117     # IOT_174
set_io -nowarn pin_fc2			118     # IOT_177
set_io -nowarn pin_dsack0		119     # IOT_178
set_io -nowarn pin_dsack1		120     # IOT_179
set_io -nowarn pin_berr			121     # IOT_181
set_io -nowarn pin_halt_out		122     # IOT_190
set_io -nowarn pin_reset_out		124     # IOT_191
set_io -nowarn pin_bg			125     # IOT_192
set_io -nowarn pin_clk			128     # IOT_197_GBIN1
set_io -nowarn pin_reset_in		129     # IOT_198_GBIN0
set_io -nowarn pin_bgack		130     # IOT_206
set_io -nowarn pin_br			134     # IOT_212
set_io -nowarn pin_ipl0			135     # IOT_213
set_io -nowarn pin_ipl1			136     # IOT_214
set_io -nowarn pin_ipl2			137     # IOT_215
set_io -nowarn pin_ad[0]		138     # IOT_216
set_io -nowarn pin_ad[1]		139     # IOT_217
set_io -nowarn pin_ad[2]		141     # IOT_219
set_io -nowarn pin_ad[3]		142     # IOT_220
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

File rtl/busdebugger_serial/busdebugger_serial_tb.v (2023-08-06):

`timescale 1ns / 1ps

module busdebugger_serial_tb();

    reg pin_clk_3_6864M = 1'b0;
    reg pin_clk_16M = 1'b0;

    reg dump_start;

    wire pin_ext_1;
    wire pin_ext_2;

    reg pin_usart1_rx;
    wire pin_usart1_tx;

    reg pin_clk = 1'b1;
    reg pin_reset_in = 1'b1;
    reg pin_as = 1'b1;
    reg pin_ds = 1'b1;
    reg pin_rw = 1'b1;
    reg [31:0] pin_ad;
    reg pin_dsack0 = 1'b1;
    reg pin_dsack1 = 1'b1;
    reg pin_berr = 1'b1;

    wire pin_send_receive;
    wire pin_data_dir;
    wire pin_data_oe;
    wire pin_addr_oe;

    wire pin_ctrl_oe;
    wire pin_alt_ctrl_oe;
    wire pin_alt_ctrl_dir1;
    wire pin_alt_ctrl_dir2;
    wire pin_al_oe;
    wire pin_al_le;

    wire pin_ext_10;

    busdebugger_serial DTS(
        .comm_clock(pin_clk_3_6864M),
        .serial_clock(pin_clk_16M),

        .dump_start(dump_start),

        .pin_ext_1(pin_ext_1),
        .pin_ext_2(pin_ext_2),

        .pin_usart1_rx(pin_usart1_rx),
        .pin_usart1_tx(pin_usart1_tx),

        .pin_clk(pin_clk),
        .pin_reset_in(pin_reset_in),
        .pin_as(pin_as),
        .pin_ds(pin_ds),
        .pin_rw(pin_rw),
        .pin_ad(pin_ad),
        .pin_dsack0(pin_dsack0),
        .pin_dsack1(pin_dsack1),
        .pin_berr(pin_berr),

        .pin_send_receive(pin_send_receive),
        .pin_data_dir(pin_data_dir),
        .pin_data_oe(pin_data_oe),
        .pin_addr_oe(pin_addr_oe),

        .pin_ctrl_oe(pin_ctrl_oe),
        .pin_alt_ctrl_oe(pin_alt_ctrl_oe),
        .pin_alt_ctrl_dir1(pin_alt_ctrl_dir1),
        .pin_alt_ctrl_dir2(pin_alt_ctrl_dir2),
        .pin_al_oe(pin_al_oe),
        .pin_al_le(pin_al_le),

        .pin_ul1(pin_ul1),
        .pin_ext_10(pin_ext_10)
    );

    initial begin
        $display("Starting");

        $dumpfile("busdebugger_serial.vcd");
        $dumpvars(0, DTS);
    end

    always
        #1 pin_clk_16M = !pin_clk_16M;

    always
        #3 pin_clk = !pin_clk;

    always
        #5 pin_clk_3_6864M = !pin_clk_3_6864M;

    initial begin
            dump_start = 1'b0;
            pin_ad = 32'h00000000;

        #80;
            pin_as = 1'b0;
            pin_ad = 1'b0;
            pin_ad = 32'h2020FFFF;
        #20
            pin_ds = 1'b0;
            pin_ad = 32'hAAAAAAAA;
        #20
            pin_as = 1'b1;
            pin_ds = 1'b1;
            pin_ad = 32'h11111111;

        #80
            pin_as = 1'b0;
            pin_rw = 1'b1;
            pin_ad = 32'h12345678;
            pin_ds = 1'b0;
        #20
            pin_ad = 32'h55555555;
        #20
            pin_as = 1'b1;
            pin_ds = 1'b1;
            pin_ad = 32'h33333333;

        #200
            dump_start = 1'b1;

        #600000 $finish;
    end
endmodule

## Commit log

2023-01-15 Added level shifting and some I/O assignments
    [Bus.kicad_sch, Fidget.kicad_sch, IO.kicad_sch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]
2023-01-15 Added oscillators
    [Fidget.kicad_sch, IO.kicad_sch]
2023-01-15 Added WIP schematic
2023-01-15 Assigned bus control signals to level shifters
    [Fidget.kicad_sch, IO.kicad_sch, LevelShifting.kicad_sch]
2023-01-15 Added address latches
    [Bus.kicad_sch, Fidget.kicad_sch, IO.kicad_sch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]
2023-01-16 Progress on sorting out the transceiver controls
    [Bus.kicad_sch, Fidget.kicad_sch, IO.kicad_sch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]
2023-01-21 Added jumper to select bus voltage
    [Bus.kicad_sch, Fidget.kicad_sch, LevelShifting.kicad_sch]
2023-01-23 Filled in more details in schematic
    [Bus.kicad_sch, Fidget.kicad_sch, IO.kicad_sch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]
2023-01-24 Got simple RTL experiment of USART<->Bus in TinyFPGA
    [Fidget.kicad_sch, IO.kicad_sch]
2023-02-06 Minor updates, and start of PCB layout
    [Bus.kicad_sch, Fidget.kicad_pcb, Fidget.kicad_sch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]
2023-02-12 More PCB layout and fixes and reassigments to the schematics
    [Bus.kicad_sch, Fidget.kicad_pcb, Fidget.kicad_sch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]
2023-02-24 Almost done Rev1 board design
    [Bus.kicad_sch, Fidget.csv, Fidget.kicad_sch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]
2023-02-28 Changed crystal footprint and minor cleanup of Rev1 PCB
    [Fidget.kicad_sch]
2023-03-05 Sent Rev.1 to production
    [IO.kicad_sch, LevelShifting.kicad_sch]
2023-04-03 The board is almost built, but tinyprog won't program it
    I seem to be missing meta data in the SPI flash
    [pins-fidget.pcf]
2023-04-08 Switched to a fork of TinyFPGA with Fidget board added
2023-04-08 Board is working with the bootloader and blinking led demo
2023-07-09 Fixed many issues with the computie bus snooper, but dump is not quite working
    I had to leave a hack in-place where the computie bus snooper needs to convert
    the 32 bit number into a list of 4 bit numbers, which seems to either require
    SystemVerilog or manually unpacking the list, which I did, but which is not
    truely parametric according to BITWIDTH.
    It seems to record the correct data, but there's a problem with the passing of
    data to the usart transmitter, which doesn't properly wait for each character
    to be sent before trying to send the next one
    [busdebugger_serial_tb.v]
2023-07-10 Modified usart tx to use state machine and added common makefile
    It prints the dump sort of correctly, but it prints double characters
    sometimes. This seems to be because the start_transmitting bit is
    always set, but trying to change that makes it send characters without
    waiting for them to be transmitted. I don't yet know the right
    pattern to be using here to make the interconnected modules work
    [busdebugger_serial_tb.v]
2023-07-15 Added a serial echo config and started adding a computie bus receiver module
    There's still lots of bugs with the snooper, and the serial tx/rx
    [busdebugger_serial_tb.v]
2023-08-03 Dump output of the bus snooper is working, but recording is not
    It now prints a header and footer, which is a single line feed, and
    the button starts the dump which proceeds until the end, but it will
    still print multiple dumps if the button is held.
    Recording doesn't work properly and using it causes the output to
    glitch, which makes me think it's continuously recording
2023-08-06 Modified to use an async fifo between snooper and dumper
    I also had to replace the generator in the memory module because it
    wasn't synthenizing properly, and I don't know why
    The interface to the ram wasn't working, which is why I replaced it
    with a fifo. The timing was off, but I know the fifo interface to
    ram works. Using the valid/ready signals for the dumper was great
    but the snooper, it isn't the best because the snooper can't wait
    for the output to be read. It has to keep up with the bus speed.
    [busdebugger_serial_tb.v]
2023-08-07 Added computie-kicad-library and updated to KiCad 7.0
    [Bus.kicad_sch, Fidget.kicad_sch, IO.kicad_sch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]
